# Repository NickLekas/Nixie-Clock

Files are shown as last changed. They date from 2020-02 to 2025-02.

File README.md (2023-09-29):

v1 is broken and required some bodge wires to work. I have not updated the schematic and PCB to correct my mistakes. It also has some deficencies in the dimming circuit resulint in a quiet, but audible whine.

v2 is in progress and will fix many issues and make the clock easier to update. It wil be using an RP2040.

Features
- Automatic time seting using GPS
- User sets their time zone using dip switches
- Tubes dim with ambient light
- Day light savings time will be controlled using a +/-1 switch 
- Plenty of test points for testing and hacking
- USB C for power and data

The goal of this is to be a program once project so the end user will never need to plug it into a computer. But if they do, the RP2040 will make firmware updates easy

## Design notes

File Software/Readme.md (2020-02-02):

This is the initial code for an Arduino Mega based Nixie tube based clock. 

This clock consists of a GPS module to set time and a DS3231SN RTC to keep track of time.

On startup, the gps module will get the current time and send it to the RTC. Once the RTC has the time, the GPS module will be powerd down to save energy.

Every night at 3am local time, the GPS will be turned back on and update the RTC time. While the DS3231SN is a very precise RTC, this is done for good measure. Depending on the clocks location, it is possible that the gps will not be able to aquire a signal. After 10 minutes of not aquiring a signal, the GPS will be turned off and an attempt to set the time will be made the next day.

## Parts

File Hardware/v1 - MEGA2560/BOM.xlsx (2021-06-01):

v1.0
Ref des | Quantity | value | Component | Package
C1, C2, C3, C4, C6, C10, C11 | 7 | 0.1uF |  | 0603 | 1
C17, C18 | 2 | 0.22uF |  | 0603 | 1
C13 | 1 | 100uF |  | 0603
C5, C9, C12, C16 | 4 | 10uF |  | 0603 | 1
C7, C8, C15 | 3 | 1uF |  | 0603 | 1
C14 | 1 | 4.7uf | 200V + | E3,5-8 | 1
R7, R8, R9, R16 | 4 | 100k | 1/3 W | 0603 | 1
R1, R3, R4, R5, R6, R10, R11, R17, R18, R19, R20, R21, R22 | 13 | 10k |  | 0603 | 1
R12, R13, R14, R15 | 4 | 10k | 1/2 W | 0805 | 1
R2 | 1 | 1M |  | 0603 | 1
D1, D2 | 2 | Green |  | 0603 | 1
U3, U4, U5, U6 | 4 |  | K155ID1 | DIP 16 | 1
U1 | 1 |  | ATmega2560-16AU | TQFP100 | 1
U2 | 1 |  | CH340C | SOP-16 |  | lcsc | https://lcsc.com/product-detail/USB-ICs_WCH-Jiangsu-Qin-Heng-CH340C_C84681.html
U8 | 1 |  | DS3231SN#T&R | SOIC-16 | 1
U12 | 1 |  | IP2721 | TSSOP-16 | 1 | lcsc | https://lcsc.com/product-detail/Interface-Specialized_INJOINIC-IP2721_C603176.html
U11 | 1 |  | L80-M39 | LCC | 1 | lcsc | https://lcsc.com/product-detail/Satellite-Positioning-Modules_Quectel-L80-M39_C133488.html
U13, U14 | 2 |  | LM340MP-5.0/NOPB | SOT-223 | 1
U9, U10 | 2 |  | MIC5205-3.3YM5-TR | SOT-23-5 |  | lcsc
U7 | 1 |  | NCH8200HV |  | 1
S1 | 1 |  | SW_DIP-8 | DIP-16 | 1
T3 | 1 |  | CSD18543Q3A | VSONP-8 | 1
T1 | 1 |  | PZTA92 | SOT-223 | 1
T2 | 1 |  | PZTA42 | SOT-223 | 1
PH1 | 1 |  | GM5539 |  | 1
BT1 | 1 |  | 1056 or CR1220-2 |  | 1
X1 | 1 |  | CSTNE16M0V53C000R0 |  | 1
J4 | 1 |  | HRO_TYPE-C-31-M-12 |  |  | lcsc | https://lcsc.com/product-detail/USB-Connectors_Hanbo-Electronic-MC-312_C961716.html
N1, N2, N3, N4 | 4 |  | ИН-8 |  | 1
v1.05
Ref des | Quantity | value | Component | Package
C1, C2, C3, C4, C6, C10, C11 | 7 | 0.1uF |  | 0603
C17, C18 | 2 | 0.22uF |  | 0603
C13 | 1 | 100uF |  | 0603
C5, C9, C12, C16 | 4 | 10uF |  | 0603
C7, C8, C15 | 3 | 1uF |  | 0603
C14 | 1 | 4.7uf | 200V + | E3,5-8
R7, R8, R9, R16 | 4 | 100k | 1/3 W | 0603
R1, R10, R11, R17, R18, R20, R22 | 7 | 10k |  | 0603
R3, R4, R5, R6, R19 | 5 | 5.1k |  | 0603
R12, R13, R14, R15 | 4 | 10k | 1/2 W | 0805
R2 | 1 | 1M |  | 0603
D1, D2 | 2 | Green |  | 0603
U3, U4, U5, U6 | 4 |  | K155ID1 | DIP 16
U1 | 1 |  | ATmega2560-16AU | TQFP100
U2 | 1 |  | CH340C | SOP-16 | lcsc | https://lcsc.com/product-detail/USB-ICs_WCH-Jiangsu-Qin-Heng-CH340C_C84681.html
U8 | 1 |  | DS3231SN#T&R | SOIC-16
U12 | 1 |  | IP2721 | TSSOP-16 | lcsc | https://lcsc.com/product-detail/Interface-Specialized_INJOINIC-IP2721_C603176.html
U11 | 1 |  | L80-M39 | LCC | lcsc | https://lcsc.com/product-detail/Satellite-Positioning-Modules_Quectel-L80-M39_C133488.html
U13, U14 | 2 |  | LM340MP-5.0/NOPB | SOT-223
U9, U10 | 2 |  | MIC5205-3.3YM5-TR | SOT-23-5 | lcsc
U7 | 1 |  | NCH8200HV
S1 | 1 |  | SW_DIP-8 | DIP-16
T3 | 1 |  | CSD18543Q3A | VSONP-8
T1 | 1 |  | PZTA92 | SOT-223
T2 | 1 |  | PZTA42 | SOT-223
PH1 | 1 |  | GM5539
BT1 | 1 |  | 1056 or CR1220-2
X1 | 1 |  | CSTNE16M0V53C000R0
J4 | 1 |  | 12402012E212A
N1, N2, N3, N4 | 4 |  | ИН-8

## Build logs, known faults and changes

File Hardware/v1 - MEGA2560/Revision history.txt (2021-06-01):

v1.0
	- Initial design
v1.05 (This version fixed some issues in v1.0 before switching to KiCad)
	- Changed all polygon pours to not have thermal connections
	- Changed D1, D2 to have 5.1k current limiting resistors
	- Added 5.1k pull downs to CC1, CC2
	- Reduced the RX voltage divider to a 10K and 5.1K
v1.1 (Carries over all fixes made in v1.0)
	- Switched design to KiCad v6/5.99

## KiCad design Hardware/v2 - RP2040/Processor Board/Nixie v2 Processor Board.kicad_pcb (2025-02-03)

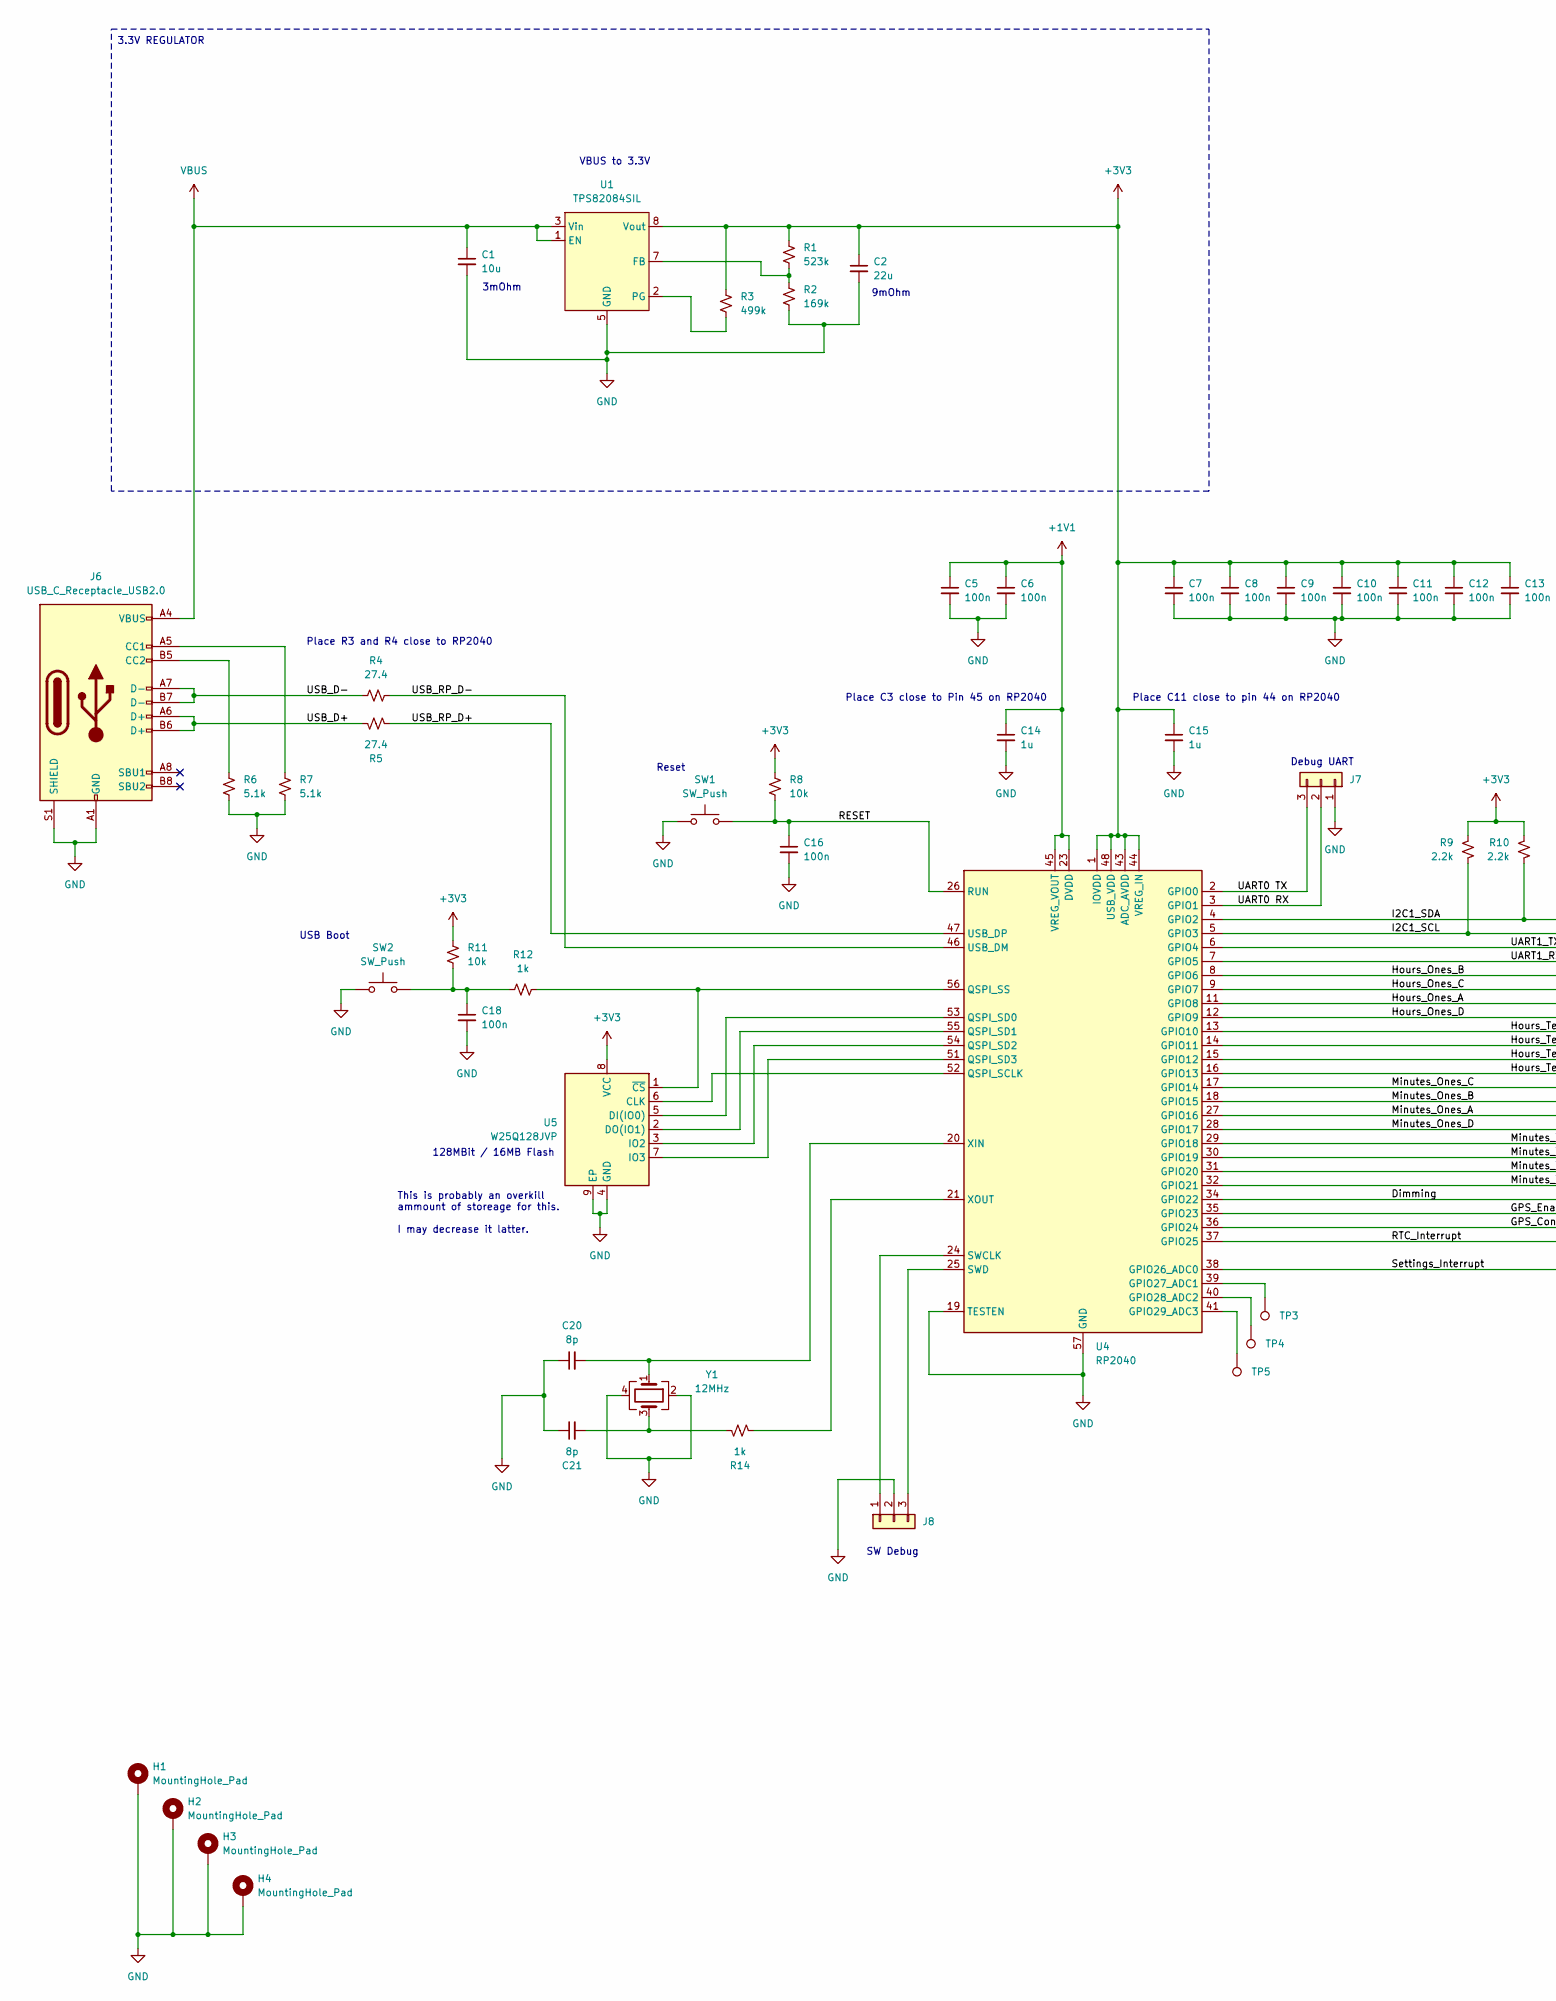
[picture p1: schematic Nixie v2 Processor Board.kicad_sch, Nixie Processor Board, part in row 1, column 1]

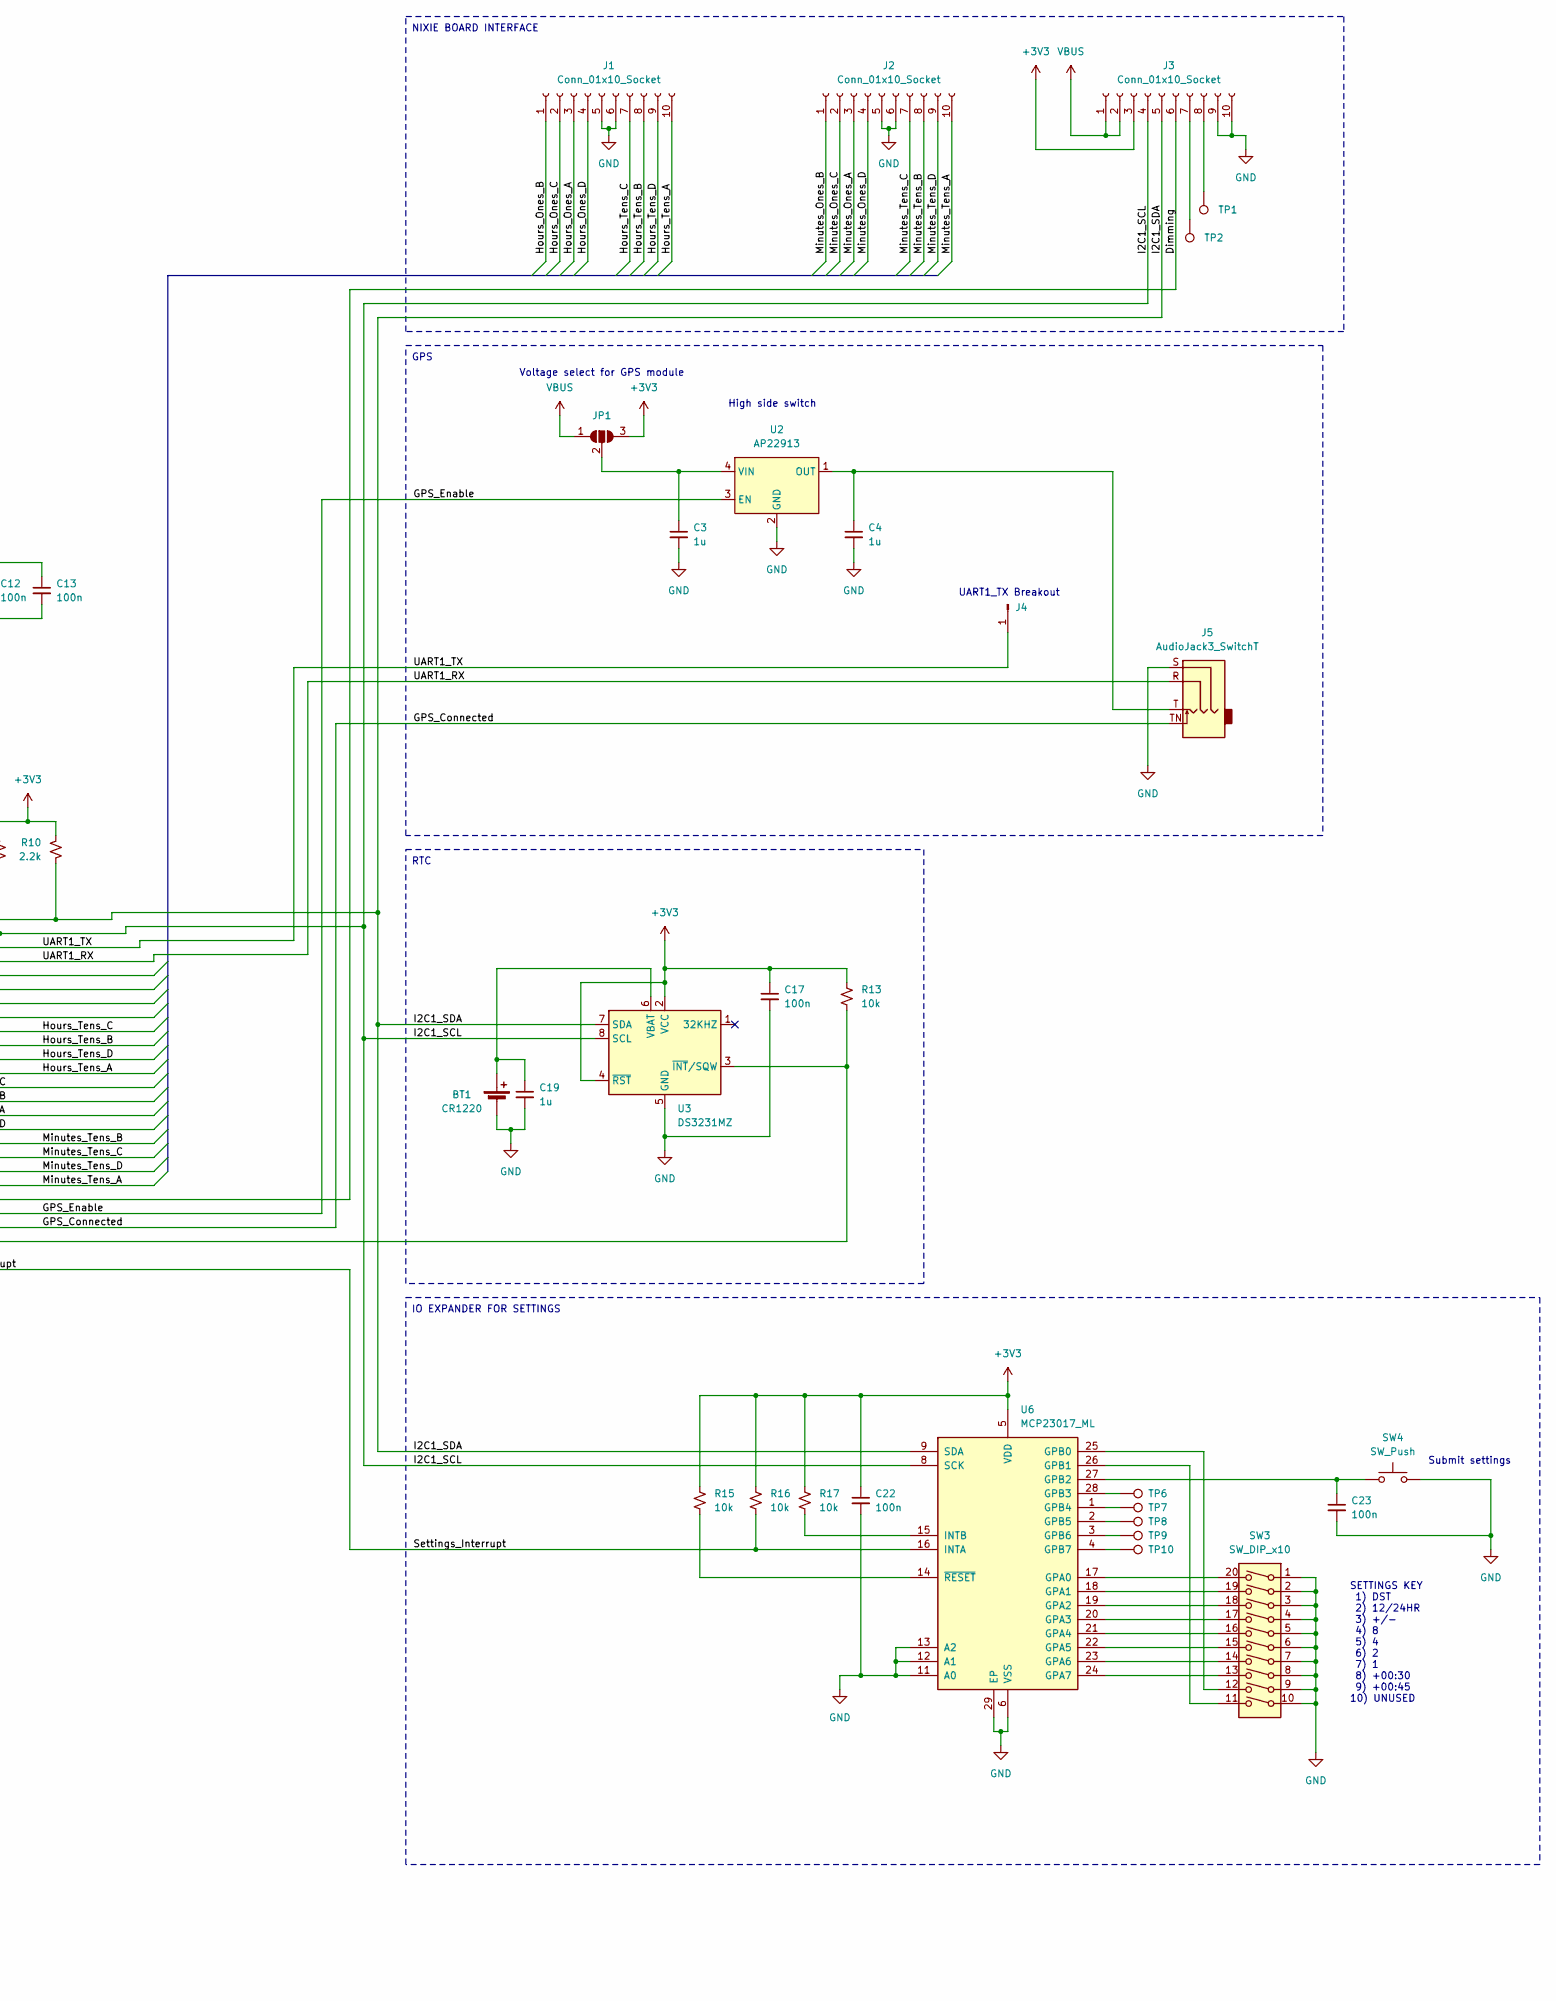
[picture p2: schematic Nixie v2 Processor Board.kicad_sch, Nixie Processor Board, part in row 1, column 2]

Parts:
BT1: CR1220; BatteryHolder_LINX_BAT-HLD-012-SMT; MPN BK-916-TR
C1: 10u; C_0603_1608Metric
C2: 22u; C_0603_1608Metric
C3, C4, C19: 1u; C_0603_1608Metric
C5, C6, C7, C8, C9, C10, C11, C12, C13: 100n; C_0402_1005Metric
C14, C15: 1u; C_0402_1005Metric
C16, C17, C18, C22, C23: 100n; C_0603_1608Metric
C20, C21: 8p; C_0402_1005Metric
H1, H2, H3, H4: MountingHole_Pad; MountingHole_3.2mm_M3_Pad_Via
J1, J2, J3: Conn_01x10_Socket; PinSocket_2x05_P2.54mm_Vertical
J4: Conn_01x01_Pin; PinHeader_1x01_P2.54mm_Vertical
J5: AudioJack3_SwitchT; Jack_3.5mm_CUI_SJ-3524-SMT_Horizontal
J6: USB_C_Receptacle_USB2.0; USB_C_Receptacle_HRO_TYPE-C-31-M-12
J7, J8: Conn_01x03_2.54mm; PinHeader_1x03_P2.54mm_Vertical
JP1: SolderJumper_3_Open; SolderJumper-3_P1.3mm_Open_RoundedPad1.0x1.5mm_NumberLabels
R1: 523k; R_0603_1608Metric
R2: 169k; R_0603_1608Metric
R3: 499k; R_0603_1608Metric
R4, R5: 27.4; R_0402_1005Metric
R6, R7: 5.1k; R_0603_1608Metric
R8, R11, R13, R15, R16, R17: 10k; R_0603_1608Metric
R9, R10: 2.2k; R_0603_1608Metric
R12: 1k; R_0603_1608Metric
R14: 1k; R_0402_1005Metric
SW1, SW2, SW4: SW_Push; SW_Push_1P1T_NO_CK_KMR2; MPN KMR213G LFG
SW3: SW_DIP_x10; SW_DIP_SPSTx10_Piano_10.8x26.96mm_W7.62mm_P2.54mm; MPN 219-10MST
TP1, TP2, TP3, TP4, TP5, TP6, TP7, TP8, TP9, TP10: TestPoint; TestPoint_Pad_D2.0mm
U1: TPS82084SIL; MicroSiP 1.33mm
U2: AP22913; SOT-23-6
U3: DS3231MZ; SOIC-8_3.9x4.9mm_P1.27mm
U4: RP2040; QFN-56-1EP_7x7mm_P0.4mm_EP3.2x3.2mm
U5: W25Q128JVP; WSON-8-1EP_6x5mm_P1.27mm_EP3.4x4.3mm
U6: MCP23017_ML; QFN-28-1EP_6x6mm_P0.65mm_EP4.25x4.25mm
Y1: 12MHz; Crystal_SMD_Abracon_ABM10-4Pin_2.5x2.0mm; MPN ABM10-166-12.000MHZ-T3

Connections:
+1V1: C5.1, C6.1, C14.1, U4.23 (DVDD), U4.45 (VREG_VOUT), U4.50 (DVDD)
+3V3: C2.1, C7.1, C8.1, C9.1, C10.1, C11.1, C12.1, C13.1, C15.1, C17.1, C22.1, J3.3, JP1.3 (B), R1.2, R3.2, R8.2, R9.1, R10.1, R11.2, R13.1, R15.1, R16.1, R17.1, U1.8 (Vout), U3.2 (VCC), U3.4 (~RST), U4.1 (IOVDD), U4.10 (IOVDD), U4.22 (IOVDD), U4.33 (IOVDD), U4.42 (IOVDD), U4.43 (ADC_AVDD), U4.44 (VREG_IN), U4.48 (USB_VDD), U4.49 (IOVDD), U5.8 (VCC), U6.5 (VDD)
/Dimming: J3.6, U4.34 (GPIO22)
/GPS_Connected: J5.TN, U4.36 (GPIO24)
/GPS_Enable: U2.3 (EN), U4.35 (GPIO23)
/Hours_Ones_A: J1.3, U4.11 (GPIO8)
/Hours_Ones_B: J1.1, U4.8 (GPIO6)
/Hours_Ones_C: J1.2, U4.9 (GPIO7)
/Hours_Ones_D: J1.4, U4.12 (GPIO9)
/Hours_Tens_A: J1.10, U4.16 (GPIO13)
/Hours_Tens_B: J1.8, U4.14 (GPIO11)
/Hours_Tens_C: J1.7, U4.13 (GPIO10)
/Hours_Tens_D: J1.9, U4.15 (GPIO12)
/I2C1_SCL: J3.4, R9.2, U3.8 (SCL), U4.5 (GPIO3), U6.8 (SCK)
/I2C1_SDA: J3.5, R10.2, U3.7 (SDA), U4.4 (GPIO2), U6.9 (SDA)
/Minutes_Ones_A: J2.3, U4.27 (GPIO16)
/Minutes_Ones_B: J2.1, U4.18 (GPIO15)
/Minutes_Ones_C: J2.2, U4.17 (GPIO14)
/Minutes_Ones_D: J2.4, U4.28 (GPIO17)
/Minutes_Tens_A: J2.10, U4.32 (GPIO21)
/Minutes_Tens_B: J2.8, U4.29 (GPIO18)
/Minutes_Tens_C: J2.7, U4.30 (GPIO19)
/Minutes_Tens_D: J2.9, U4.31 (GPIO20)
/RESET: C16.1, R8.1, SW1.2, U4.26 (RUN)
/RTC_Interrupt: R13.2, U3.3 (~INT/SQW), U4.37 (GPIO25)
/Settings_Interrupt: R16.2, U4.38 (GPIO26_ADC0), U6.16 (INTA)
/UART0 RX: J7.2, U4.3 (GPIO1)
/UART0 TX: J7.3, U4.2 (GPIO0)
/UART1_RX: J5.R, U4.7 (GPIO5)
/UART1_TX: J4.1, U4.6 (GPIO4)
/USB_D+: J6.A6 (D+), J6.B6 (D+), R5.2
/USB_D-: J6.A7 (D-), J6.B7 (D-), R4.2
/USB_RP_D+: R5.1, U4.47 (USB_DP)
/USB_RP_D-: R4.1, U4.46 (USB_DM)
GND: BT1.2 (-), C1.2, C2.2, C3.2, C4.2, C5.2, C6.2, C7.2, C8.2, C9.2, C10.2, C11.2, C12.2, C13.2, C14.2, C15.2, C16.2, C17.2, C18.2, C19.2, C20.1, C21.1, C22.2, C23.2, H1.1, H2.1, H3.1, H4.1, J1.5, J1.6, J2.5, J2.6, J3.9, J3.10, J5.S, J6.A1 (GND), J6.A12 (GND), J6.B1 (GND), J6.B12 (GND), J6.S1 (SHIELD), J7.1, J8.2, R2.1, R6.1, R7.1, SW1.1, SW2.1, SW3.1, SW3.2, SW3.3, SW3.4, SW3.5, SW3.6, SW3.7, SW3.8, SW3.9, SW3.10, SW4.2, U1.5 (GND), U1.6 (GND), U1.9 (GND), U2.2 (GND), U2.5 (GND), U3.5 (GND), U4.19 (TESTEN), U4.57 (GND), U5.4 (GND), U5.9 (EP), U6.6 (VSS), U6.11 (A0), U6.12 (A1), U6.13 (A2), U6.29 (EP), Y1.2, Y1.4
unnamed: BT1.1 (+), C19.1, U3.6 (VBAT)
unnamed: C18.1, R11.1, R12.2, SW2.2
unnamed: C21.2, R14.2, Y1.3
unnamed: J3.7, TP2.1
unnamed: J3.8, TP1.1
unnamed: J6.A5 (CC1), R7.2
unnamed: J6.B5 (CC2), R6.2
unnamed: J8.1, U4.24 (SWCLK)
unnamed: J8.3, U4.25 (SWD)
unnamed: C3.1, JP1.2 (C), U2.4 (VIN), U2.6 (VIN)
unnamed: R1.1, R2.2, U1.7 (FB)
unnamed: R3.1, U1.2 (PG)
unnamed: C4.1, J5.T, U2.1 (OUT)
unnamed: TP3.1, U4.39 (GPIO27_ADC1)
unnamed: TP4.1, U4.40 (GPIO28_ADC2)
unnamed: TP5.1, U4.41 (GPIO29_ADC3)
unnamed: U4.52 (QSPI_SCLK), U5.6 (CLK)
unnamed: U4.53 (QSPI_SD0), U5.5 (DI(IO0))
unnamed: U4.55 (QSPI_SD1), U5.2 (DO(IO1))
unnamed: U4.54 (QSPI_SD2), U5.3 (IO2)
unnamed: U4.51 (QSPI_SD3), U5.7 (IO3)
unnamed: R12.1, U4.56 (QSPI_SS), U5.1 (~CS)
unnamed: C20.2, U4.20 (XIN), Y1.1
unnamed: R14.1, U4.21 (XOUT)
unnamed: SW3.20, U6.17 (GPA0)
unnamed: SW3.19, U6.18 (GPA1)
unnamed: SW3.18, U6.19 (GPA2)
unnamed: SW3.17, U6.20 (GPA3)
unnamed: SW3.16, U6.21 (GPA4)
unnamed: SW3.15, U6.22 (GPA5)
unnamed: SW3.14, U6.23 (GPA6)
unnamed: SW3.13, U6.24 (GPA7)
unnamed: SW3.12, U6.25 (GPB0)
unnamed: SW3.11, U6.26 (GPB1)
unnamed: C23.1, SW4.1, U6.27 (GPB2)
unnamed: TP6.1, U6.28 (GPB3)
unnamed: TP7.1, U6.1 (GPB4)
unnamed: TP8.1, U6.2 (GPB5)
unnamed: TP9.1, U6.3 (GPB6)
unnamed: TP10.1, U6.4 (GPB7)
unnamed: R17.2, U6.15 (INTB)
unnamed: R15.2, U6.14 (~RESET)
VBUS: C1.1, J3.1, J3.2, J6.A4 (VBUS), J6.A9 (VBUS), J6.B4 (VBUS), J6.B9 (VBUS), JP1.1 (A), U1.1 (EN), U1.3 (Vin), U1.4 (Vin)

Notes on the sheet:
SW Debug
Place C11 close to pin 44 on RP2040
9mOhm
This is probably an overkill ammount of storeage for this. I may decrease it latter.
RTC
3mOhm
Voltage select for GPS module
GPS
Debug UART
Submit settings
High side switch
USB Boot
Place C3 close to Pin 45 on RP2040
Place R3 and R4 close to RP2040
128MBit / 16MB Flash
NIXIE BOARD INTERFACE
UART1_TX Breakout
3.3V REGULATOR
SETTINGS KEY 1) DST 2) 12/24HR 3) +/- 4) 8 5) 4 6) 2 7) 1 8) +00:30 9) +00:45 10) UNUSED
VBUS to 3.3V
IO EXPANDER FOR SETTINGS
Reset

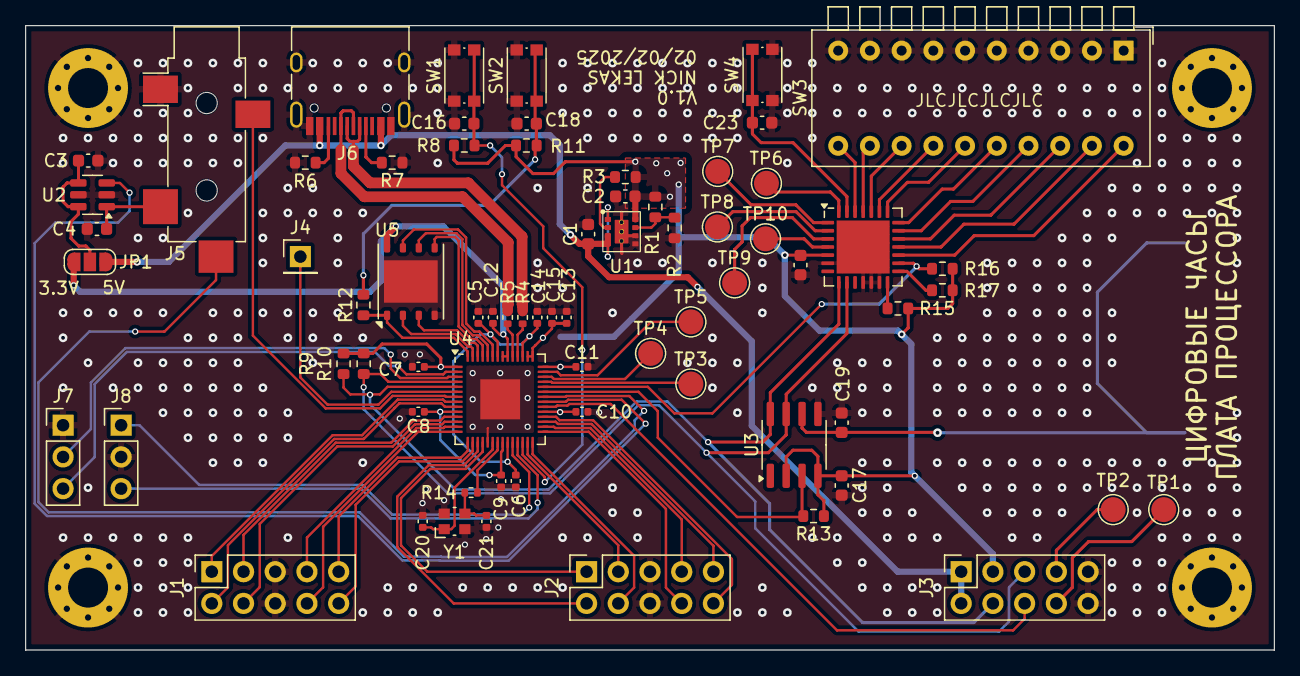
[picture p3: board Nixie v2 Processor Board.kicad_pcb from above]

Board: 2 copper layers, 100.0 x 50.0 mm, 75 parts (1 on the bottom side), 78 nets.

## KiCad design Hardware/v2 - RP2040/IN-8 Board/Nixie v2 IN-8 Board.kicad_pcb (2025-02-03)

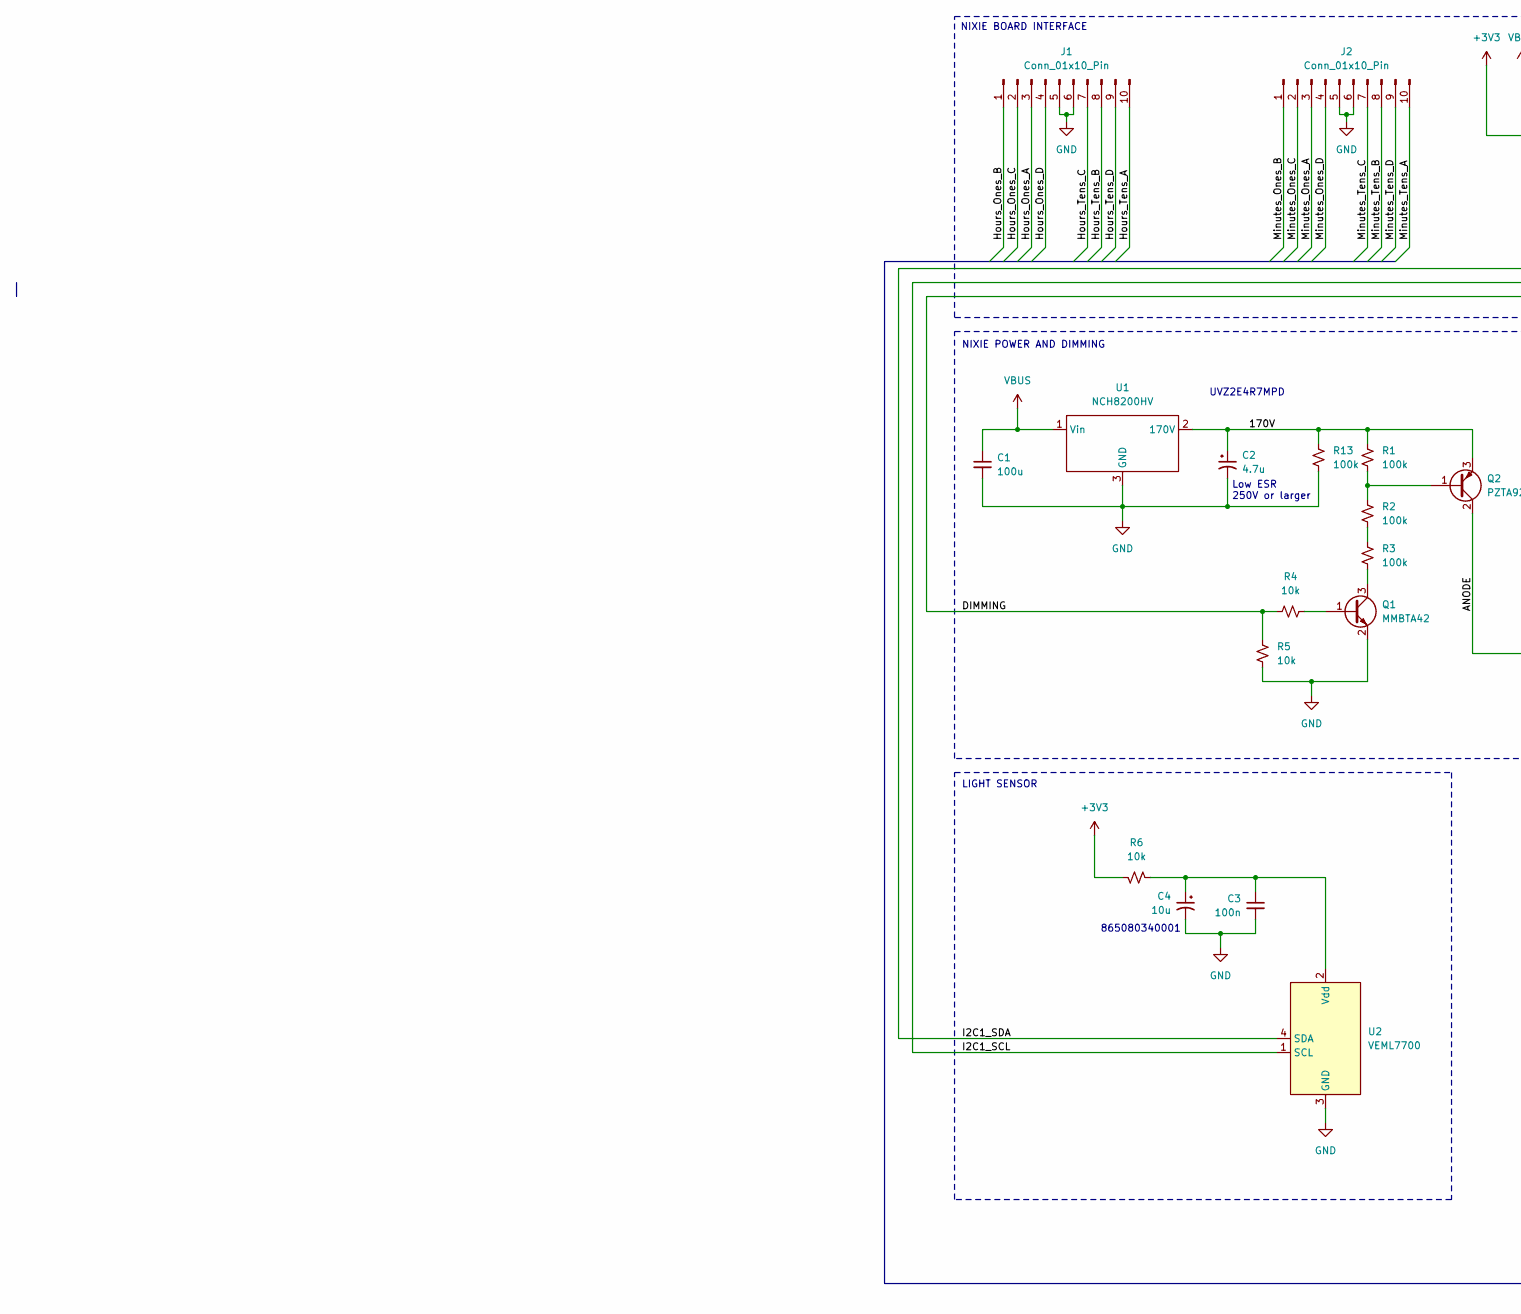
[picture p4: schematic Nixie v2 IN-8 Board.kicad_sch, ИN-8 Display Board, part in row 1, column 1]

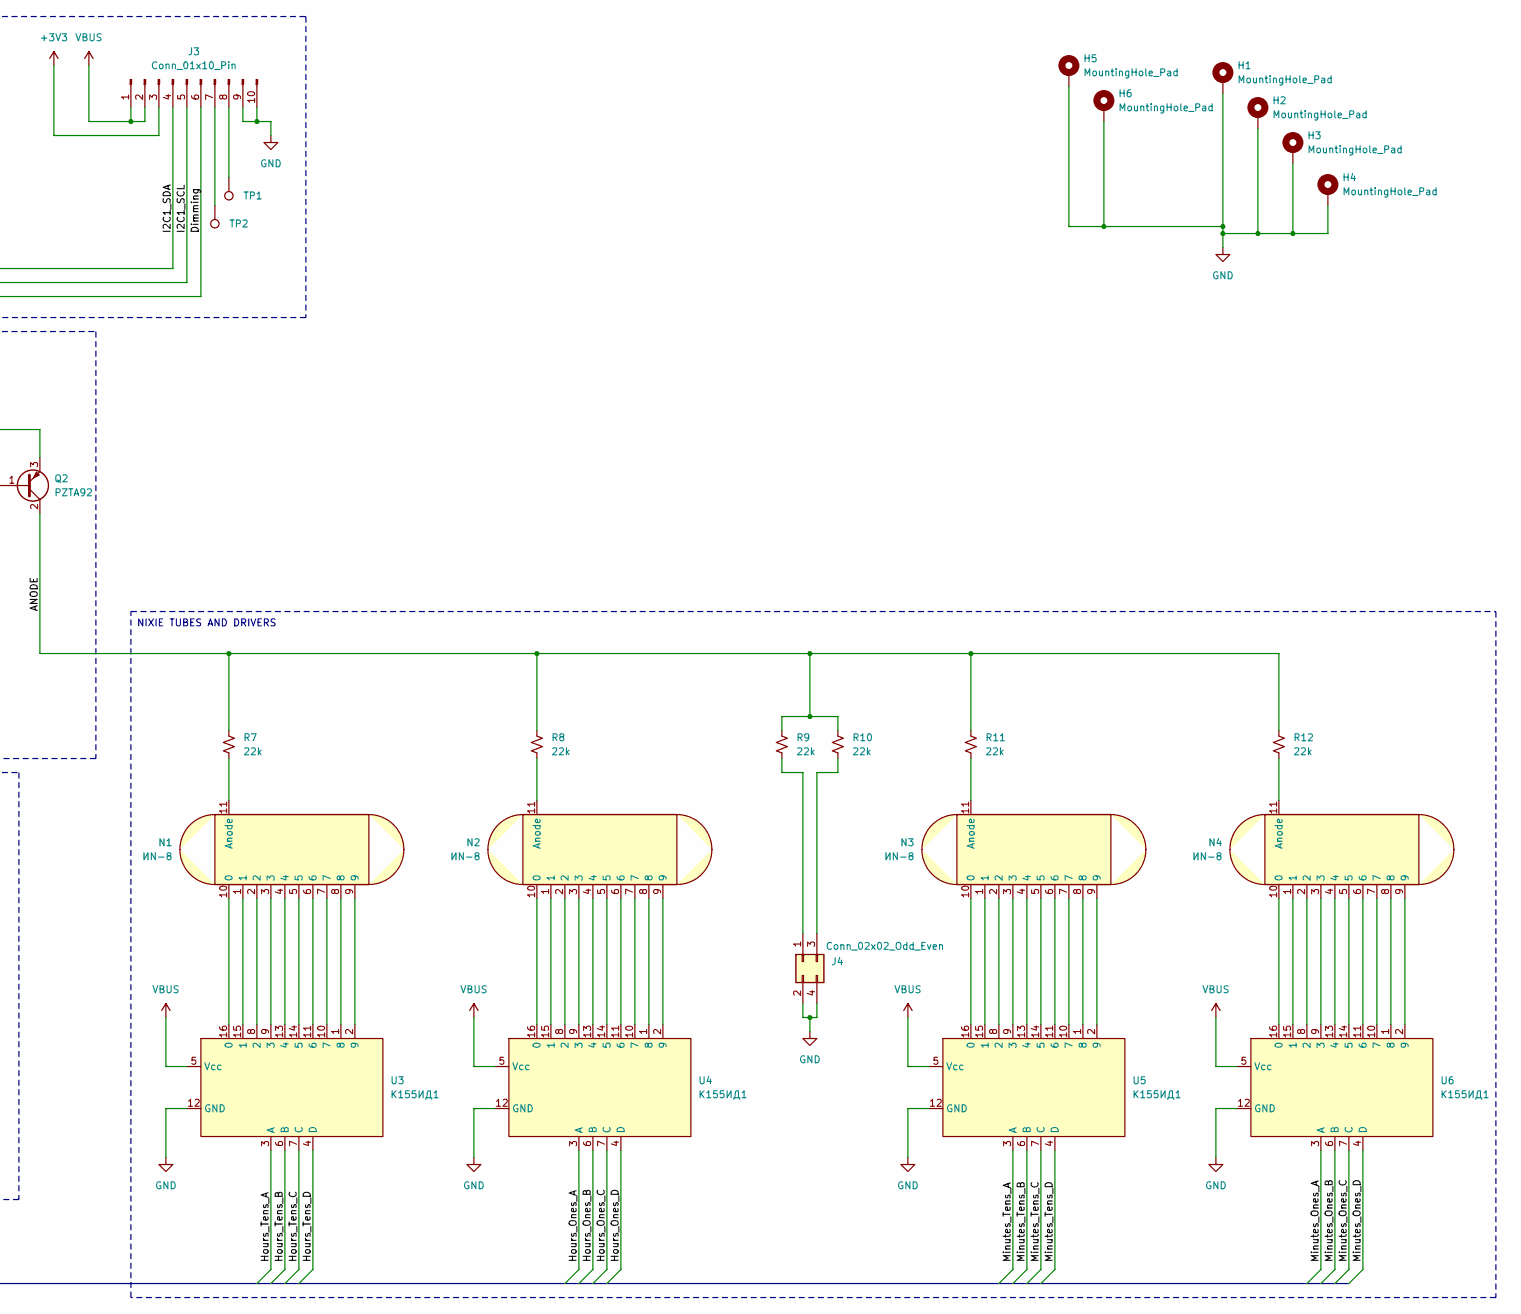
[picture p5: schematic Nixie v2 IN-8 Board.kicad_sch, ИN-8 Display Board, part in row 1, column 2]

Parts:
C1: 100u; C_0603_1608Metric
C2: 4.7u; CP_Radial_D8.0mm_P3.50mm
C3: 100n; C_0603_1608Metric
C4: 10u; CP_Elec_4x5.4
H1, H2, H3, H4, H5, H6: MountingHole_Pad; MountingHole_3.2mm_M3_Pad_Via
J1, J2, J3: Conn_01x10_Pin; PinHeader_2x05_P2.54mm_Vertical
J4: Conn_02x02_Odd_Even; PinSocket_2x02_P2.54mm_Vertical
N1, N2, N3, N4: ИN-8
Q1: MMBTA42; SOT-23
Q2: PZTA92; SOT-223-3_TabPin2
R1, R2, R3: 100k; R_0603_1608Metric
R4, R5, R6: 10k; R_0603_1608Metric
R7, R8, R9, R10, R11, R12: 22k; R_0805_2012Metric
R13: 100k; R_0805_2012Metric
TP1, TP2: TestPoint; TestPoint_Pad_D2.0mm
U1: NCH8200HV
U2: VEML7700; VEML7700-TV
U3, U4, U5, U6: К155ИД1; DIP-16_W7.62mm

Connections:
+3V3: J3.3, R6.2
/170V: C2.1, Q2.3 (E), R1.1, R13.1, U1.2 (170V)
/ANODE: Q2.2 (C), R7.1, R8.1, R9.1, R10.1, R11.1, R12.1
/DIMMING: J3.6, R4.1, R5.1
/Hours_Ones_A: J1.3, U4.3 (A)
/Hours_Ones_B: J1.1, U4.6 (B)
/Hours_Ones_C: J1.2, U4.7 (C)
/Hours_Ones_D: J1.4, U4.4 (D)
/Hours_Tens_A: J1.10, U3.3 (A)
/Hours_Tens_B: J1.8, U3.6 (B)
/Hours_Tens_C: J1.7, U3.7 (C)
/Hours_Tens_D: J1.9, U3.4 (D)
/I2C1_SCL: J3.5, U2.1 (SCL)
/I2C1_SDA: J3.4, U2.4 (SDA)
/Minutes_Ones_A: J2.3, U6.3 (A)
/Minutes_Ones_B: J2.1, U6.6 (B)
/Minutes_Ones_C: J2.2, U6.7 (C)
/Minutes_Ones_D: J2.4, U6.4 (D)
/Minutes_Tens_A: J2.10, U5.3 (A)
/Minutes_Tens_B: J2.8, U5.6 (B)
/Minutes_Tens_C: J2.7, U5.7 (C)
/Minutes_Tens_D: J2.9, U5.4 (D)
GND: C1.2, C2.2, C3.2, C4.2, H1.1, H2.1, H3.1, H4.1, H5.1, H6.1, J1.5, J1.6, J2.5, J2.6, J3.9, J3.10, J4.2, J4.4, Q1.2 (E), R5.2, R13.2, U1.3 (GND), U1.4 (GND), U2.3 (GND), U3.12 (GND), U4.12 (GND), U5.12 (GND), U6.12 (GND)
unnamed: J3.7, TP2.1
unnamed: J3.8, TP1.1
unnamed: J4.1, R9.2
unnamed: J4.3, R10.2
unnamed: N1.10 (0), U3.16 (0)
unnamed: N1.11 (Anode), R7.2
unnamed: N2.10 (0), U4.16 (0)
unnamed: N2.11 (Anode), R8.2
unnamed: N3.10 (0), U5.16 (0)
unnamed: N3.11 (Anode), R11.2
unnamed: N4.10 (0), U6.16 (0)
unnamed: N4.11 (Anode), R12.2
unnamed: Q1.1 (B), R4.2
unnamed: Q1.3 (C), R3.2
unnamed: Q2.1 (B), R1.2, R2.1
unnamed: R2.2, R3.1
unnamed: C3.1, C4.1, R6.1, U2.2 (Vdd)
unnamed: N1.1, U3.15 (1)
unnamed: N1.2, U3.8 (2)
unnamed: N1.3, U3.9 (3)
unnamed: N1.4, U3.13 (4)
unnamed: N1.5, U3.14 (5)
unnamed: N1.6, U3.11 (6)
unnamed: N1.7, U3.10 (7)
unnamed: N1.8, U3.1 (8)
unnamed: N1.9, U3.2 (9)
unnamed: N2.1, U4.15 (1)
unnamed: N2.2, U4.8 (2)
unnamed: N2.3, U4.9 (3)
unnamed: N2.4, U4.13 (4)
unnamed: N2.5, U4.14 (5)
unnamed: N2.6, U4.11 (6)
unnamed: N2.7, U4.10 (7)
unnamed: N2.8, U4.1 (8)
unnamed: N2.9, U4.2 (9)
unnamed: N3.1, U5.15 (1)
unnamed: N3.2, U5.8 (2)
unnamed: N3.3, U5.9 (3)
unnamed: N3.4, U5.13 (4)
unnamed: N3.5, U5.14 (5)
unnamed: N3.6, U5.11 (6)
unnamed: N3.7, U5.10 (7)
unnamed: N3.8, U5.1 (8)
unnamed: N3.9, U5.2 (9)
unnamed: N4.1, U6.15 (1)
unnamed: N4.2, U6.8 (2)
unnamed: N4.3, U6.9 (3)
unnamed: N4.4, U6.13 (4)
unnamed: N4.5, U6.14 (5)
unnamed: N4.6, U6.11 (6)
unnamed: N4.7, U6.10 (7)
unnamed: N4.8, U6.1 (8)
unnamed: N4.9, U6.2 (9)
VBUS: C1.1, J3.1, J3.2, U1.1 (Vin), U3.5 (Vcc), U4.5 (Vcc), U5.5 (Vcc), U6.5 (Vcc)

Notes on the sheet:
NIXIE POWER AND DIMMING
LIGHT SENSOR
NIXIE BOARD INTERFACE
Low ESR 250V or larger
NIXIE TUBES AND DRIVERS
UVZ2E4R7MPD
865080340001

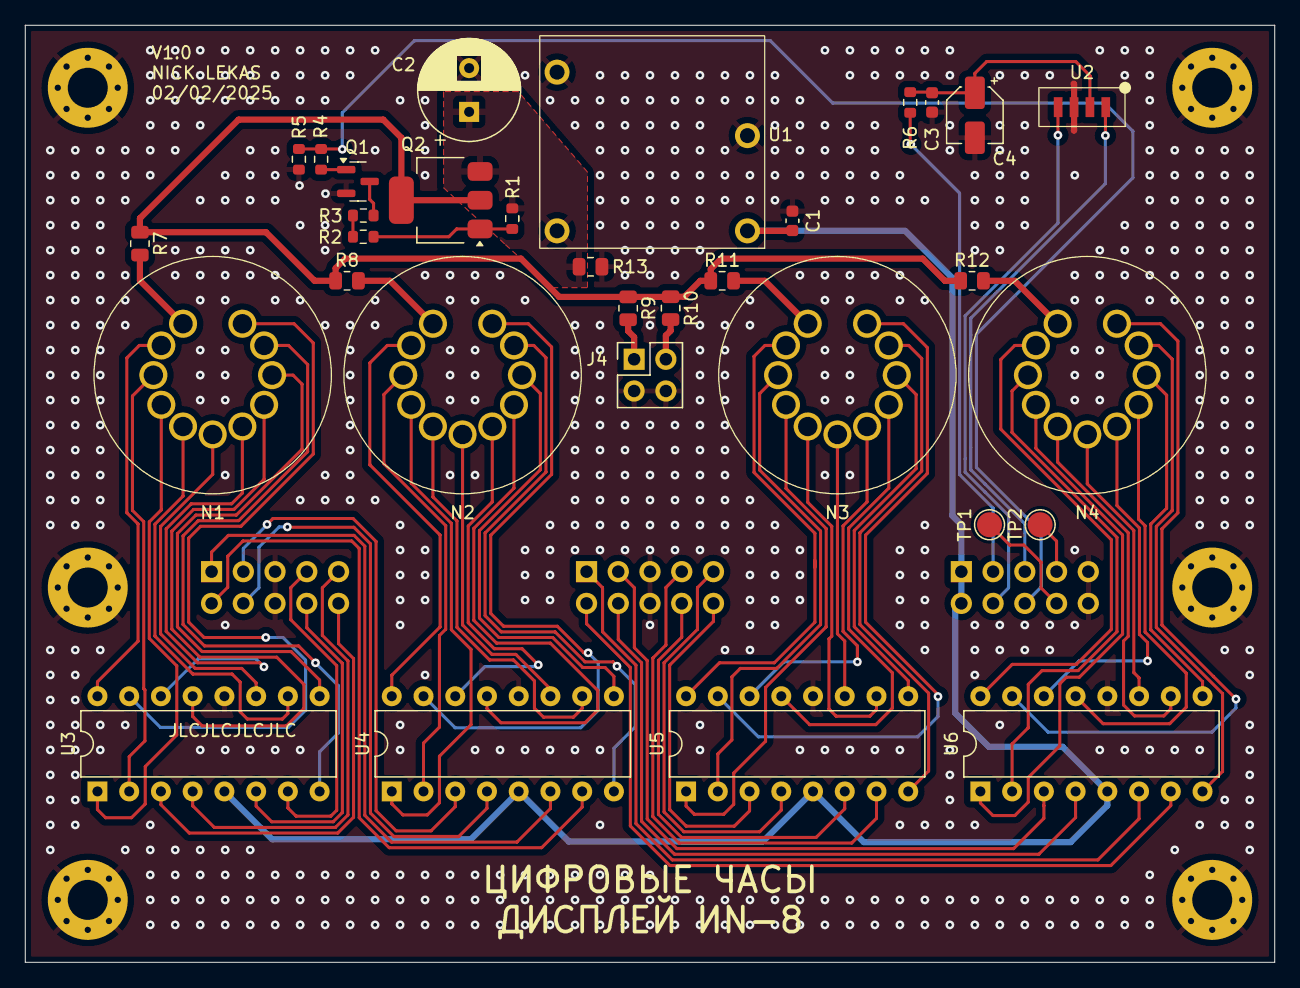
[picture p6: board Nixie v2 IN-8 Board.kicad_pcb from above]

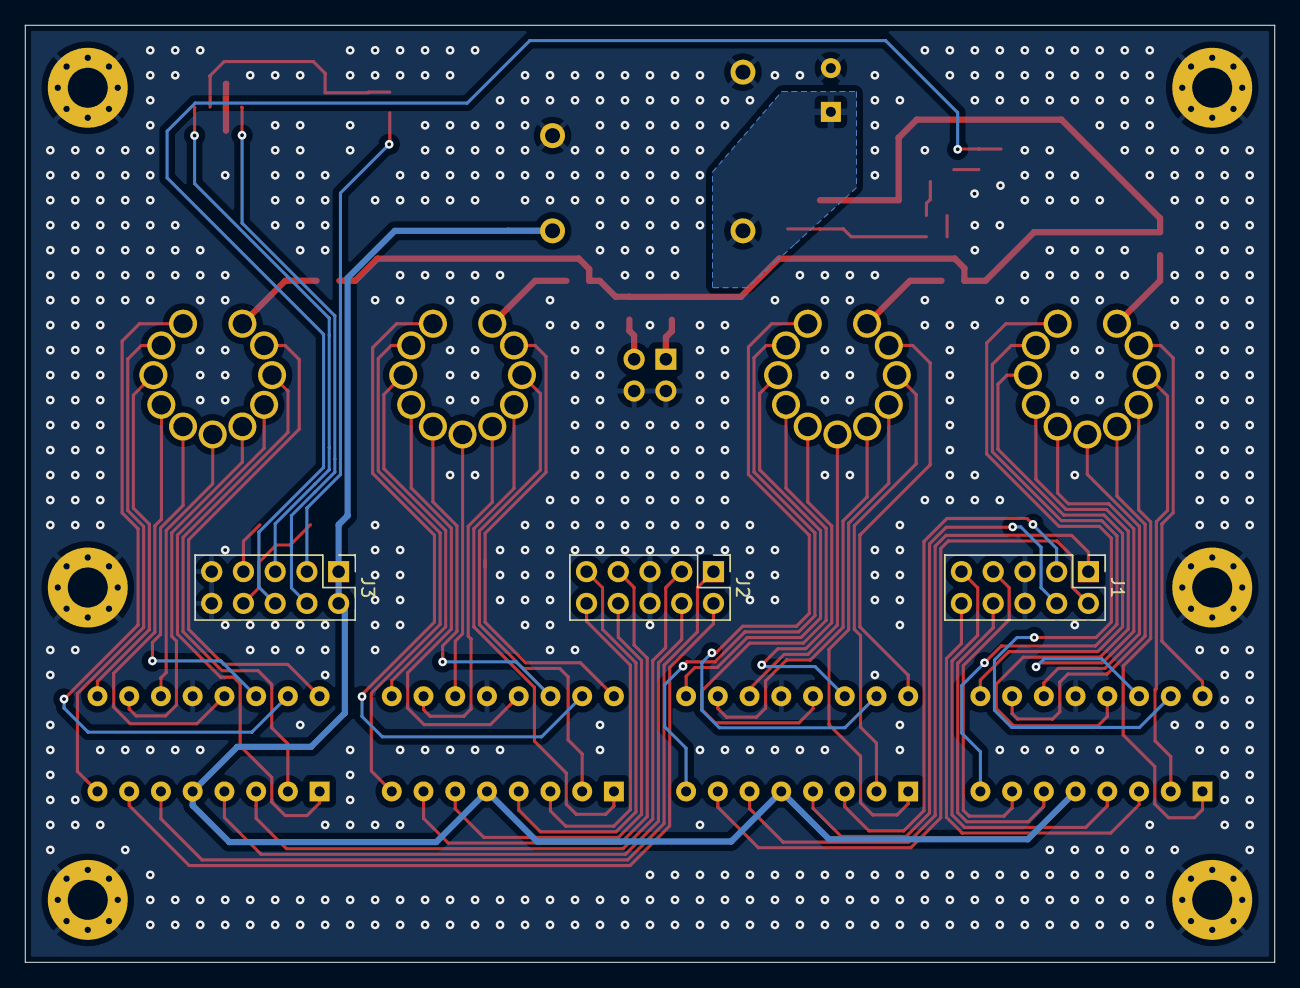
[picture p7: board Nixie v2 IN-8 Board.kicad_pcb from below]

Board: 2 copper layers, 100.0 x 75.0 mm, 41 parts (3 on the bottom side), 77 nets.

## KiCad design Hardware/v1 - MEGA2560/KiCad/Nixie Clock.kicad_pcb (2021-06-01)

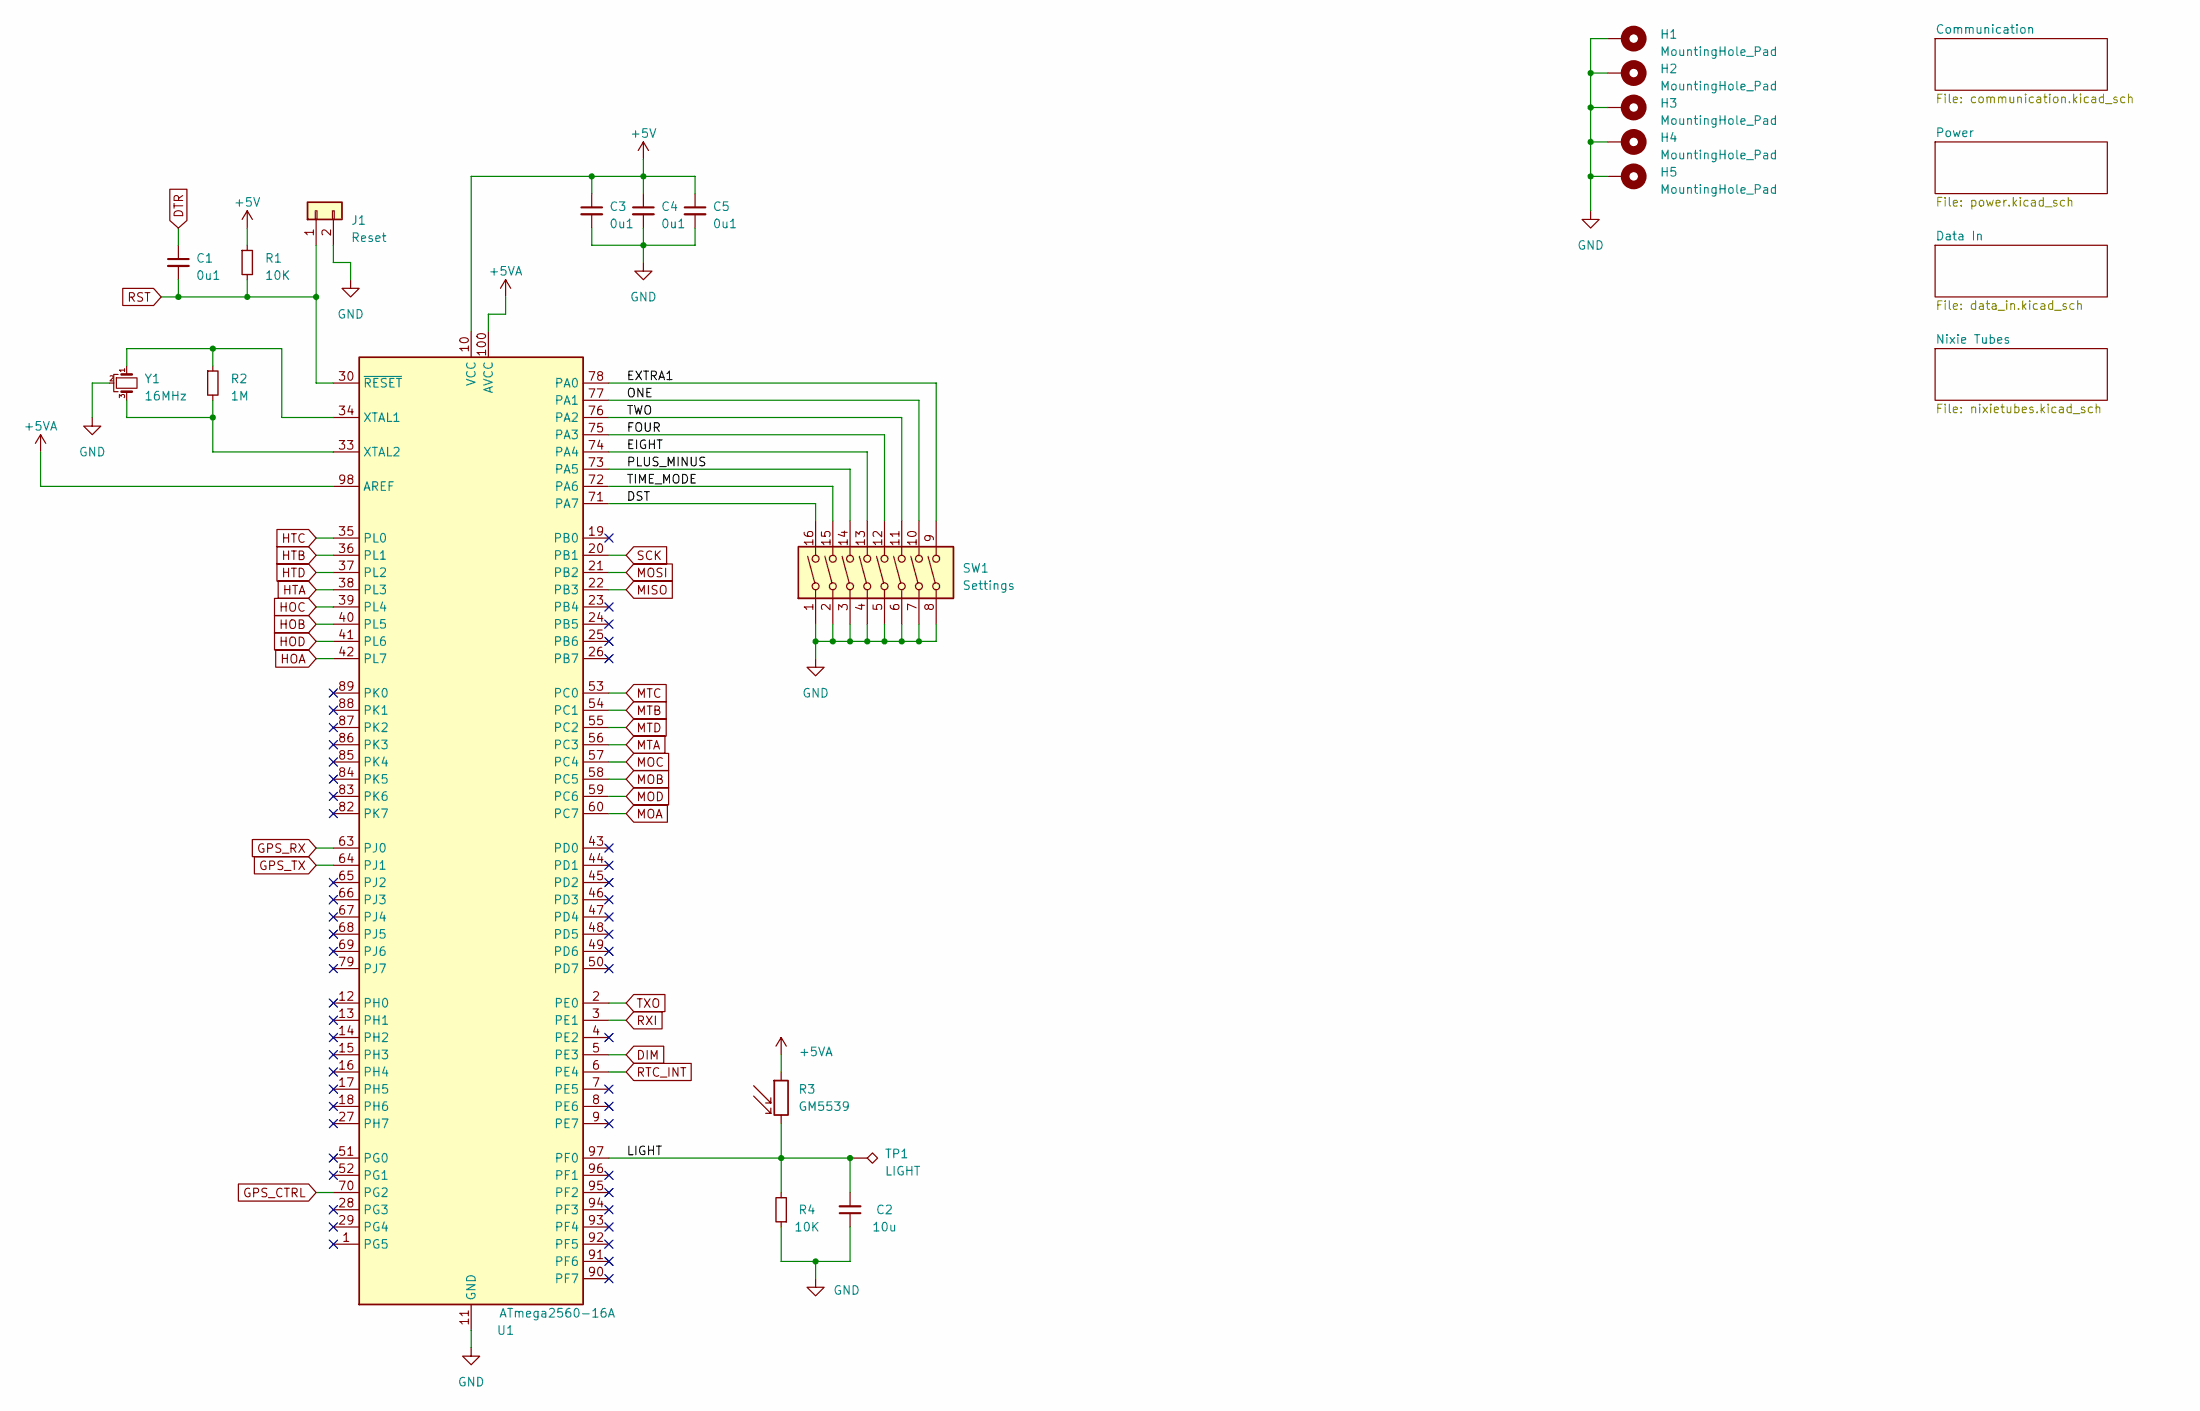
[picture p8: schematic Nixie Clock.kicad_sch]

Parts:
C1, C3, C4, C5: 0u1; C_0603_1608Metric
C2: 10u; C_0603_1608Metric
H1, H2, H3, H4, H5: MountingHole_Pad; MountingHole_3.2mm_M3_Pad_Via
J1: Reset; PinSocket_1x02_P2.54mm_Vertical
R1, R4: 10K; R_0603_1608Metric
R2: 1M; R_0603_1608Metric
R3: GM5539; R_LDR_5.1x4.3mm_P3.4mm_Vertical
SW1: Settings; SW_DIP_SPSTx08_Slide_9.78x22.5mm_W7.62mm_P2.54mm
TP1: LIGHT; TestPoint_THTPad_D2.0mm_Drill0.9mm
U1: ATmega2560-16A; TQFP-100_14x14mm_P0.5mm
Y1: 16MHz; Resonator_SMD_Murata_CSTxExxV-3Pin_3.0x1.1mm

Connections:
+5V: C3.1, C4.1, C5.1, R1.1, U1.10 (VCC), U1.31 (VCC), U1.61 (VCC), U1.80 (VCC); also elsewhere on the board
+5VA: R3.1, U1.98 (AREF), U1.100 (AVCC); also elsewhere on the board
/DST: SW1.16, U1.71 (PA7)
/EIGHT: SW1.13, U1.74 (PA4)
/EXTRA1: SW1.9, U1.78 (PA0)
/FOUR: SW1.12, U1.75 (PA3)
/LIGHT: C2.2, R3.2, R4.2, TP1.1, U1.97 (PF0)
/ONE: SW1.10, U1.77 (PA1)
/PLUS_MINUS: SW1.14, U1.73 (PA5)
/TIME_MODE: SW1.15, U1.72 (PA6)
/TWO: SW1.11, U1.76 (PA2)
DIM: U1.5 (PE3); also elsewhere on the board
DTR: C1.1; also elsewhere on the board
GND: C2.1, C3.2, C4.2, C5.2, H1.1, H2.1, H3.1, H4.1, H5.1, J1.2, R4.1, SW1.1, SW1.2, SW1.3, SW1.4, SW1.5, SW1.6, SW1.7, SW1.8, U1.11 (GND), U1.32 (GND), U1.62 (GND), U1.81 (GND), U1.99 (GND), Y1.2; also elsewhere on the board
GPS_CTRL: U1.70 (PG2); also elsewhere on the board
GPS_RX: U1.63 (PJ0); also elsewhere on the board
GPS_TX: U1.64 (PJ1); also elsewhere on the board
HOA: U1.42 (PL7); also elsewhere on the board
HOB: U1.40 (PL5); also elsewhere on the board
HOC: U1.39 (PL4); also elsewhere on the board
HOD: U1.41 (PL6); also elsewhere on the board
HTA: U1.38 (PL3); also elsewhere on the board
HTB: U1.36 (PL1); also elsewhere on the board
HTC: U1.35 (PL0); also elsewhere on the board
HTD: U1.37 (PL2); also elsewhere on the board
MISO: U1.22 (PB3); also elsewhere on the board
MOA: U1.60 (PC7); also elsewhere on the board
MOB: U1.58 (PC5); also elsewhere on the board
MOC: U1.57 (PC4); also elsewhere on the board
MOD: U1.59 (PC6); also elsewhere on the board
MOSI: U1.21 (PB2); also elsewhere on the board
MTA: U1.56 (PC3); also elsewhere on the board
MTB: U1.54 (PC1); also elsewhere on the board
MTC: U1.53 (PC0); also elsewhere on the board
MTD: U1.55 (PC2); also elsewhere on the board
unnamed: R2.1, U1.34 (XTAL1), Y1.1
unnamed: R2.2, U1.33 (XTAL2), Y1.3
RST: C1.2, J1.1, R1.2, U1.30 (~RESET); also elsewhere on the board
RTC_INT: U1.6 (PE4); also elsewhere on the board
RXI: U1.3 (PE1); also elsewhere on the board
SCK: U1.20 (PB1); also elsewhere on the board
TXO: U1.2 (PE0); also elsewhere on the board

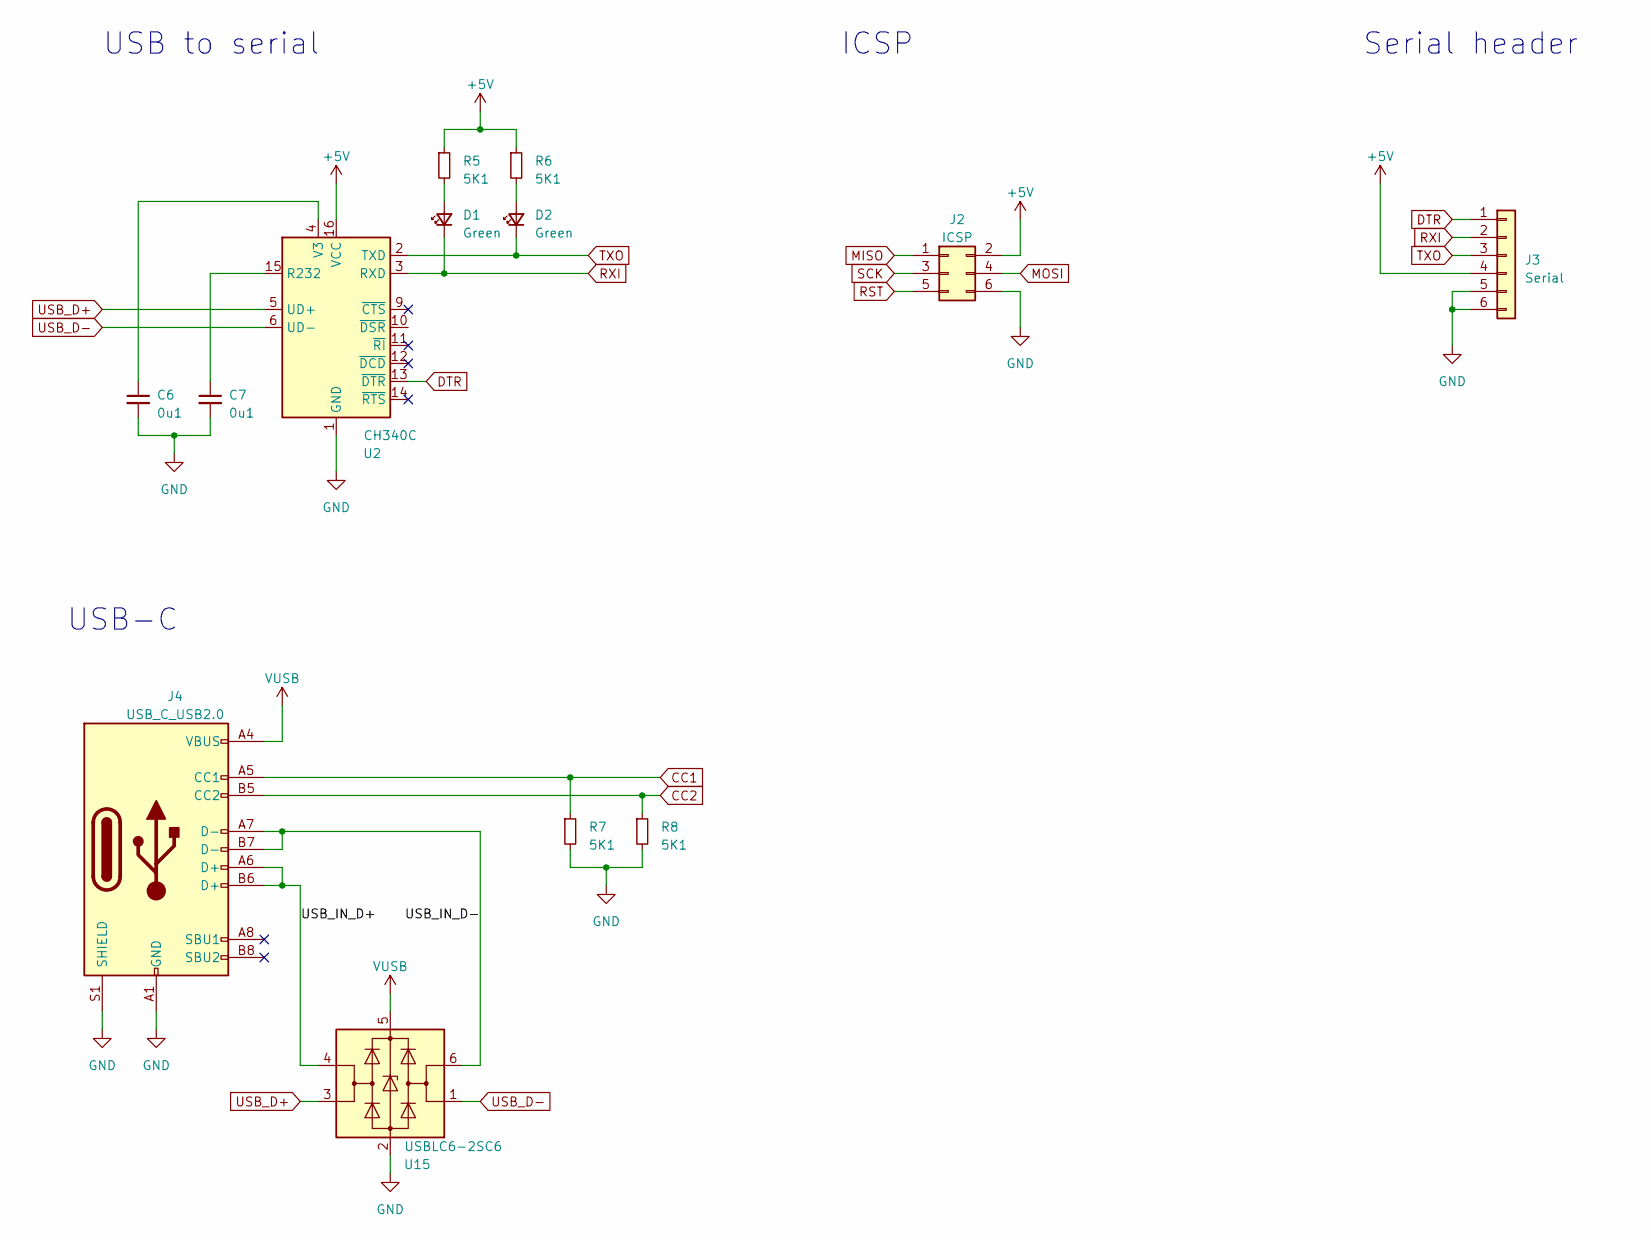
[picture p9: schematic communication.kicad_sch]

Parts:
C6, C7: 0u1; C_0603_1608Metric
D1, D2: Green; LED_0603_1608Metric
J2: ICSP; PinSocket_2x03_P2.54mm_Vertical
J3: Serial; PinSocket_1x06_P2.54mm_Vertical
J4: USB_C_USB2.0; USB_C_Receptacle_HRO_TYPE-C-31-M-12
R5, R6, R7, R8: 5K1; R_0603_1608Metric
U2: CH340C; SOIC-16_3.9x9.9mm_P1.27mm
U15: USBLC6-2SC6; SOT-23-6

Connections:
+5V: J2.2, J3.4, R5.1, R6.1, U2.16 (VCC); also elsewhere on the board
/Communication/USB_IN_D+: J4.A6 (D+), J4.B6 (D+), U15.4 (I/O2)
/Communication/USB_IN_D-: J4.A7 (D-), J4.B7 (D-), U15.6 (I/O1)
CC1: J4.A5 (CC1), R7.1; also elsewhere on the board
CC2: J4.B5 (CC2), R8.1; also elsewhere on the board
DTR: J3.1, U2.13 (~DTR); also elsewhere on the board
GND: C6.2, C7.2, J2.6, J3.5, J3.6, J4.A1 (GND), J4.A12 (GND), J4.B1 (GND), J4.B12 (GND), J4.S1 (SHIELD), R7.2, R8.2, U2.1 (GND), U15.2 (GND); also elsewhere on the board
MISO: J2.1; also elsewhere on the board
MOSI: J2.4; also elsewhere on the board
unnamed: C6.1, U2.4 (V3)
unnamed: C7.1, U2.15 (R232)
unnamed: D1.2 (A), R5.2
unnamed: D2.2 (A), R6.2
RST: J2.5; also elsewhere on the board
RXI: D1.1 (K), J3.2, U2.3 (RXD); also elsewhere on the board
SCK: J2.3; also elsewhere on the board
TXO: D2.1 (K), J3.3, U2.2 (TXD); also elsewhere on the board
USB_D+: U2.5 (UD+), U15.3 (I/O2)
USB_D-: U2.6 (UD-), U15.1 (I/O1)
VUSB: J4.A4 (VBUS), J4.A9 (VBUS), J4.B4 (VBUS), J4.B9 (VBUS), U15.5 (VBUS); also elsewhere on the board

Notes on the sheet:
USB-C
USB to serial
ICSP
Serial header

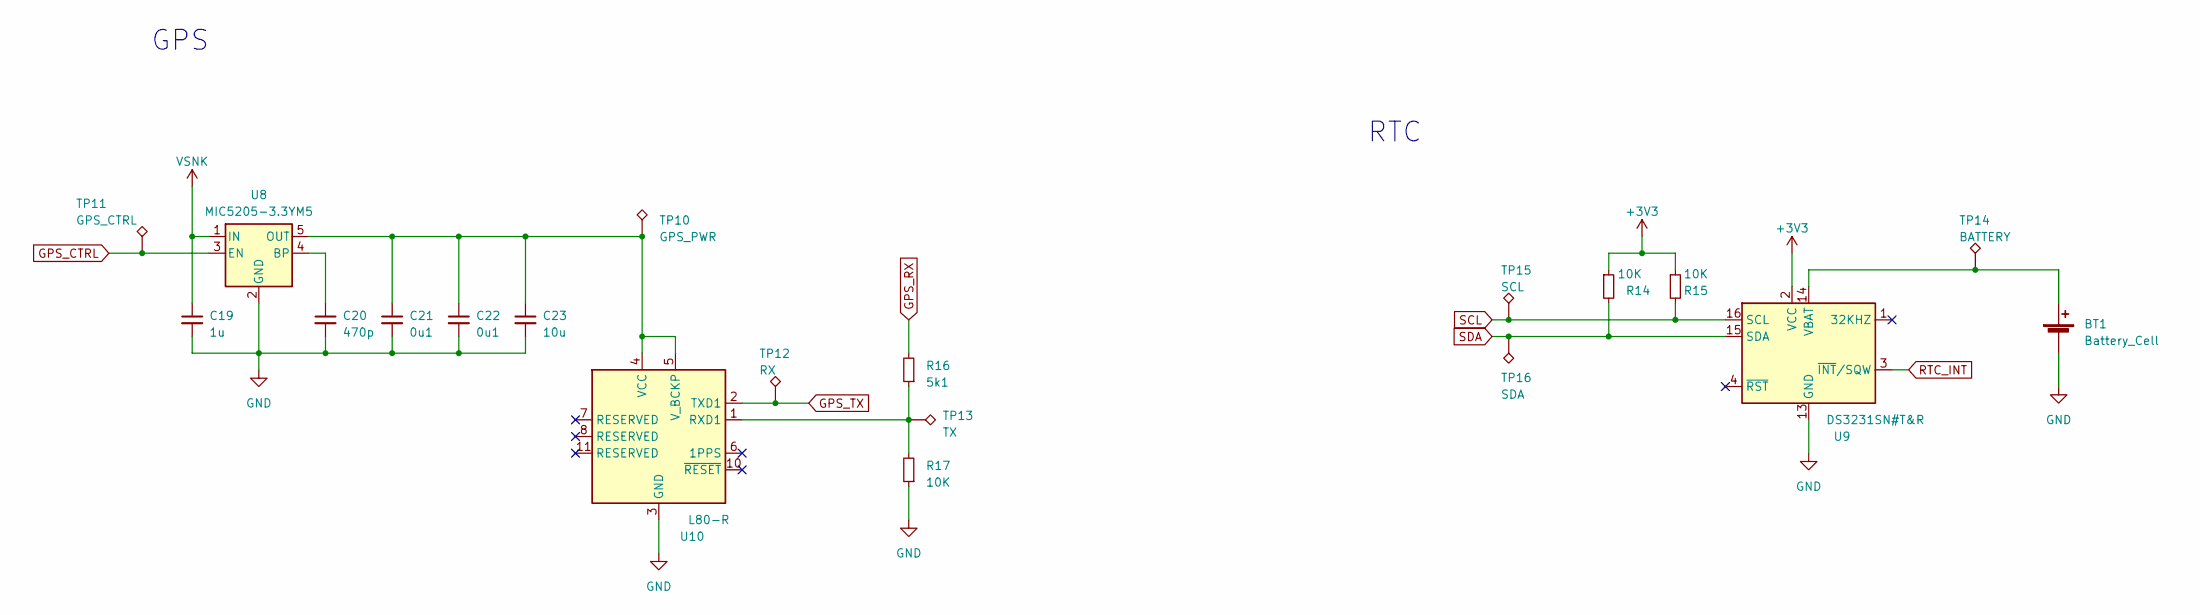
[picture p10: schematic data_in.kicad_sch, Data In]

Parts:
BT1: Battery_Cell; BatteryHolder_LINX_BAT-HLD-012-SMT
C19: 1u; C_0603_1608Metric
C20: 470p; C_0603_1608Metric
C21, C22: 0u1; C_0603_1608Metric
C23: 10u; C_0603_1608Metric
R14, R15, R17: 10K; R_0603_1608Metric
R16: 5k1; R_0603_1608Metric
TP10: GPS_PWR; TestPoint_THTPad_D2.0mm_Drill0.9mm
TP11: GPS_CTRL; TestPoint_THTPad_D2.0mm_Drill0.9mm
TP12: RX; TestPoint_THTPad_D2.0mm_Drill0.9mm
TP13: TX; TestPoint_THTPad_D2.0mm_Drill0.9mm
TP14: BATTERY; TestPoint_THTPad_D2.0mm_Drill0.9mm
TP15: SCL; TestPoint_THTPad_D2.0mm_Drill0.9mm
TP16: SDA; TestPoint_THTPad_D2.0mm_Drill0.9mm
U8: MIC5205-3.3YM5; SOT-23-5
U9: DS3231SN#T&R; SOIC-16W_7.5x10.3mm_P1.27mm
U10: L80-R; Quectel_L80-R

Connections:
+3V3: R14.1, R15.1, U9.2 (VCC); also elsewhere on the board
GND: BT1.2 (-), C19.2, C20.2, C21.2, C22.2, C23.2, R17.1, U8.2 (GND), U9.5 (GND), U9.6 (GND), U9.7 (GND), U9.8 (GND), U9.9 (GND), U9.10 (GND), U9.11 (GND), U9.12 (GND), U9.13 (GND), U10.3 (GND), U10.12 (GND); also elsewhere on the board
GPS_CTRL: TP11.1, U8.3 (EN); also elsewhere on the board
GPS_RX: R16.2; also elsewhere on the board
GPS_TX: TP12.1, U10.2 (TXD1); also elsewhere on the board
unnamed: BT1.1 (+), TP14.1, U9.14 (VBAT)
unnamed: C20.1, U8.4 (BP)
unnamed: C21.1, C22.1, C23.1, TP10.1, U8.5 (OUT), U10.4 (VCC), U10.5 (V_BCKP)
unnamed: R16.1, R17.2, TP13.1, U10.1 (RXD1)
RTC_INT: U9.3 (~INT~/SQW); also elsewhere on the board
SCL: R15.2, TP15.1, U9.16 (SCL)
SDA: R14.2, TP16.1, U9.15 (SDA)
VSNK: C19.1, U8.1 (IN); also elsewhere on the board

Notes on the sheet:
GPS
RTC

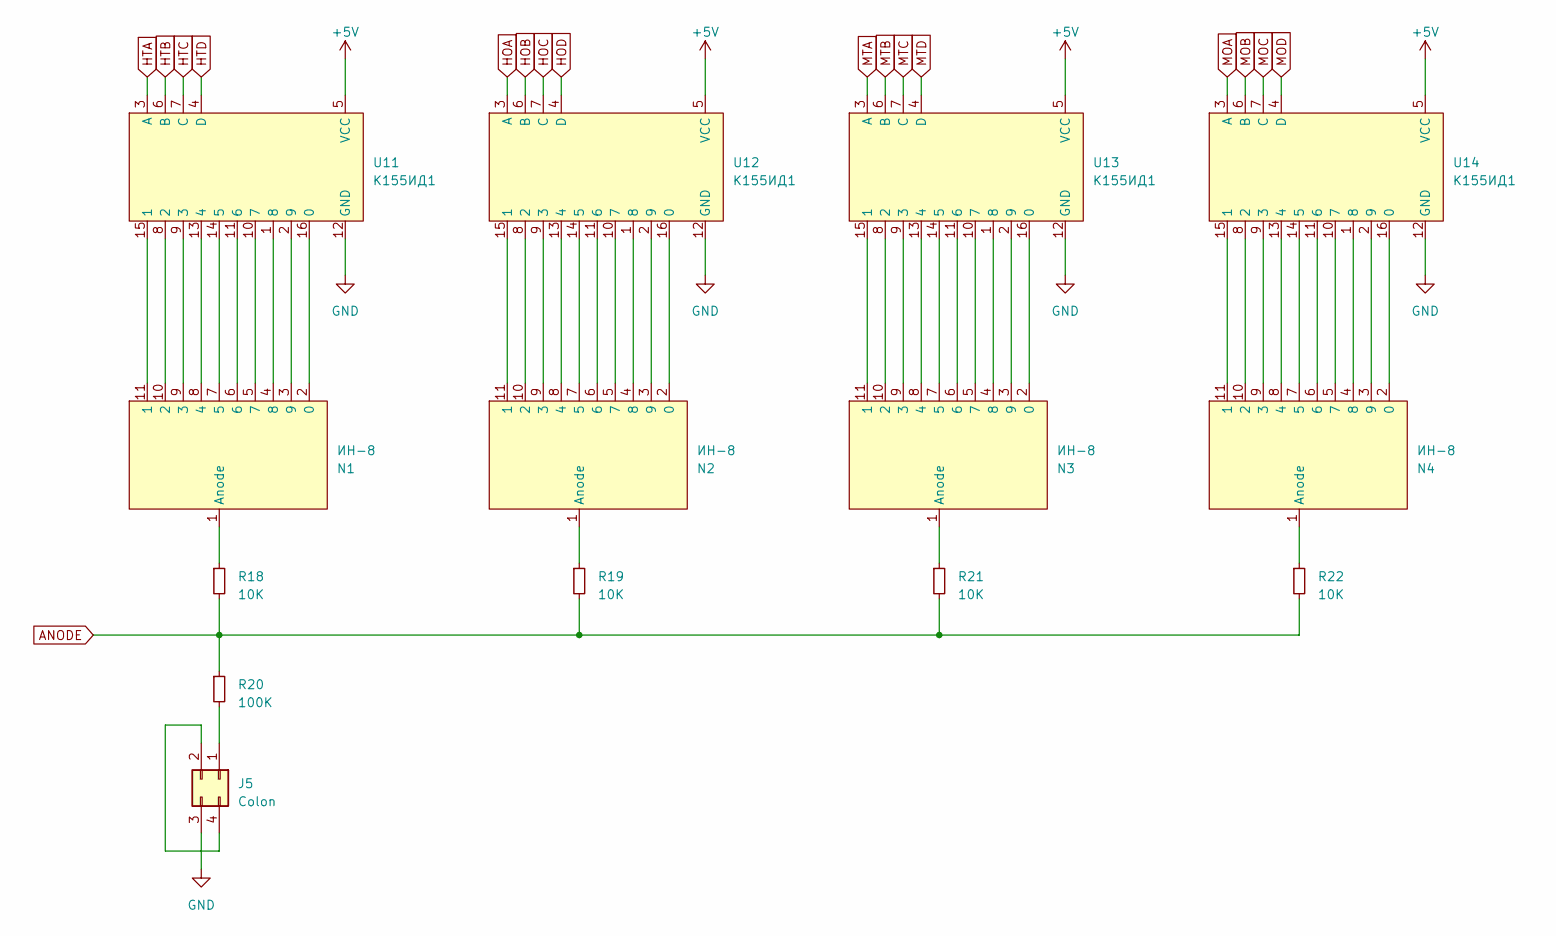
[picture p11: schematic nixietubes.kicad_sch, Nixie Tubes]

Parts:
J5: Colon; PinSocket_2x02_P2.54mm_Vertical
N1, N2, N3, N4: ИН-8
R18, R19, R21, R22: 10K; R_0805_2012Metric
R20: 100K; R_0603_1608Metric
U11, U12, U13, U14: К155ИД1; DIP-16_W7.62mm

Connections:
+5V: U11.5 (VCC), U12.5 (VCC), U13.5 (VCC), U14.5 (VCC); also elsewhere on the board
ANODE: R18.2, R19.2, R20.1, R21.2, R22.2; also elsewhere on the board
GND: J5.3, U11.12 (GND), U12.12 (GND), U13.12 (GND), U14.12 (GND); also elsewhere on the board
HOA: U12.3 (A); also elsewhere on the board
HOB: U12.6 (B); also elsewhere on the board
HOC: U12.7 (C); also elsewhere on the board
HOD: U12.4 (D); also elsewhere on the board
HTA: U11.3 (A); also elsewhere on the board
HTB: U11.6 (B); also elsewhere on the board
HTC: U11.7 (C); also elsewhere on the board
HTD: U11.4 (D); also elsewhere on the board
MOA: U14.3 (A); also elsewhere on the board
MOB: U14.6 (B); also elsewhere on the board
MOC: U14.7 (C); also elsewhere on the board
MOD: U14.4 (D); also elsewhere on the board
MTA: U13.3 (A); also elsewhere on the board
MTB: U13.6 (B); also elsewhere on the board
MTC: U13.7 (C); also elsewhere on the board
MTD: U13.4 (D); also elsewhere on the board
unnamed: J5.1, R20.2
unnamed: J5.2, J5.4
unnamed: N1.1 (Anode), R18.1
unnamed: N1.2 (0), U11.16 (0)
unnamed: N1.3 (9), U11.2 (9)
unnamed: N1.4 (8), U11.1 (8)
unnamed: N1.5 (7), U11.10 (7)
unnamed: N1.6, U11.11 (6)
unnamed: N1.7 (5), U11.14 (5)
unnamed: N1.8 (4), U11.13 (4)
unnamed: N1.9 (3), U11.9 (3)
unnamed: N1.10 (2), U11.8 (2)
unnamed: N1.11 (1), U11.15 (1)
unnamed: N2.1 (Anode), R19.1
unnamed: N2.2 (0), U12.16 (0)
unnamed: N2.3 (9), U12.2 (9)
unnamed: N2.4 (8), U12.1 (8)
unnamed: N2.5 (7), U12.10 (7)
unnamed: N2.6, U12.11 (6)
unnamed: N2.7 (5), U12.14 (5)
unnamed: N2.8 (4), U12.13 (4)
unnamed: N2.9 (3), U12.9 (3)
unnamed: N2.10 (2), U12.8 (2)
unnamed: N2.11 (1), U12.15 (1)
unnamed: N3.1 (Anode), R21.1
unnamed: N3.2 (0), U13.16 (0)
unnamed: N3.3 (9), U13.2 (9)
unnamed: N3.4 (8), U13.1 (8)
unnamed: N3.5 (7), U13.10 (7)
unnamed: N3.6, U13.11 (6)
unnamed: N3.7 (5), U13.14 (5)
unnamed: N3.8 (4), U13.13 (4)
unnamed: N3.9 (3), U13.9 (3)
unnamed: N3.10 (2), U13.8 (2)
unnamed: N3.11 (1), U13.15 (1)
unnamed: N4.1 (Anode), R22.1
unnamed: N4.2 (0), U14.16 (0)
unnamed: N4.3 (9), U14.2 (9)
unnamed: N4.4 (8), U14.1 (8)
unnamed: N4.5 (7), U14.10 (7)
unnamed: N4.6, U14.11 (6)
unnamed: N4.7 (5), U14.14 (5)
unnamed: N4.8 (4), U14.13 (4)
unnamed: N4.9 (3), U14.9 (3)
unnamed: N4.10 (2), U14.8 (2)
unnamed: N4.11 (1), U14.15 (1)

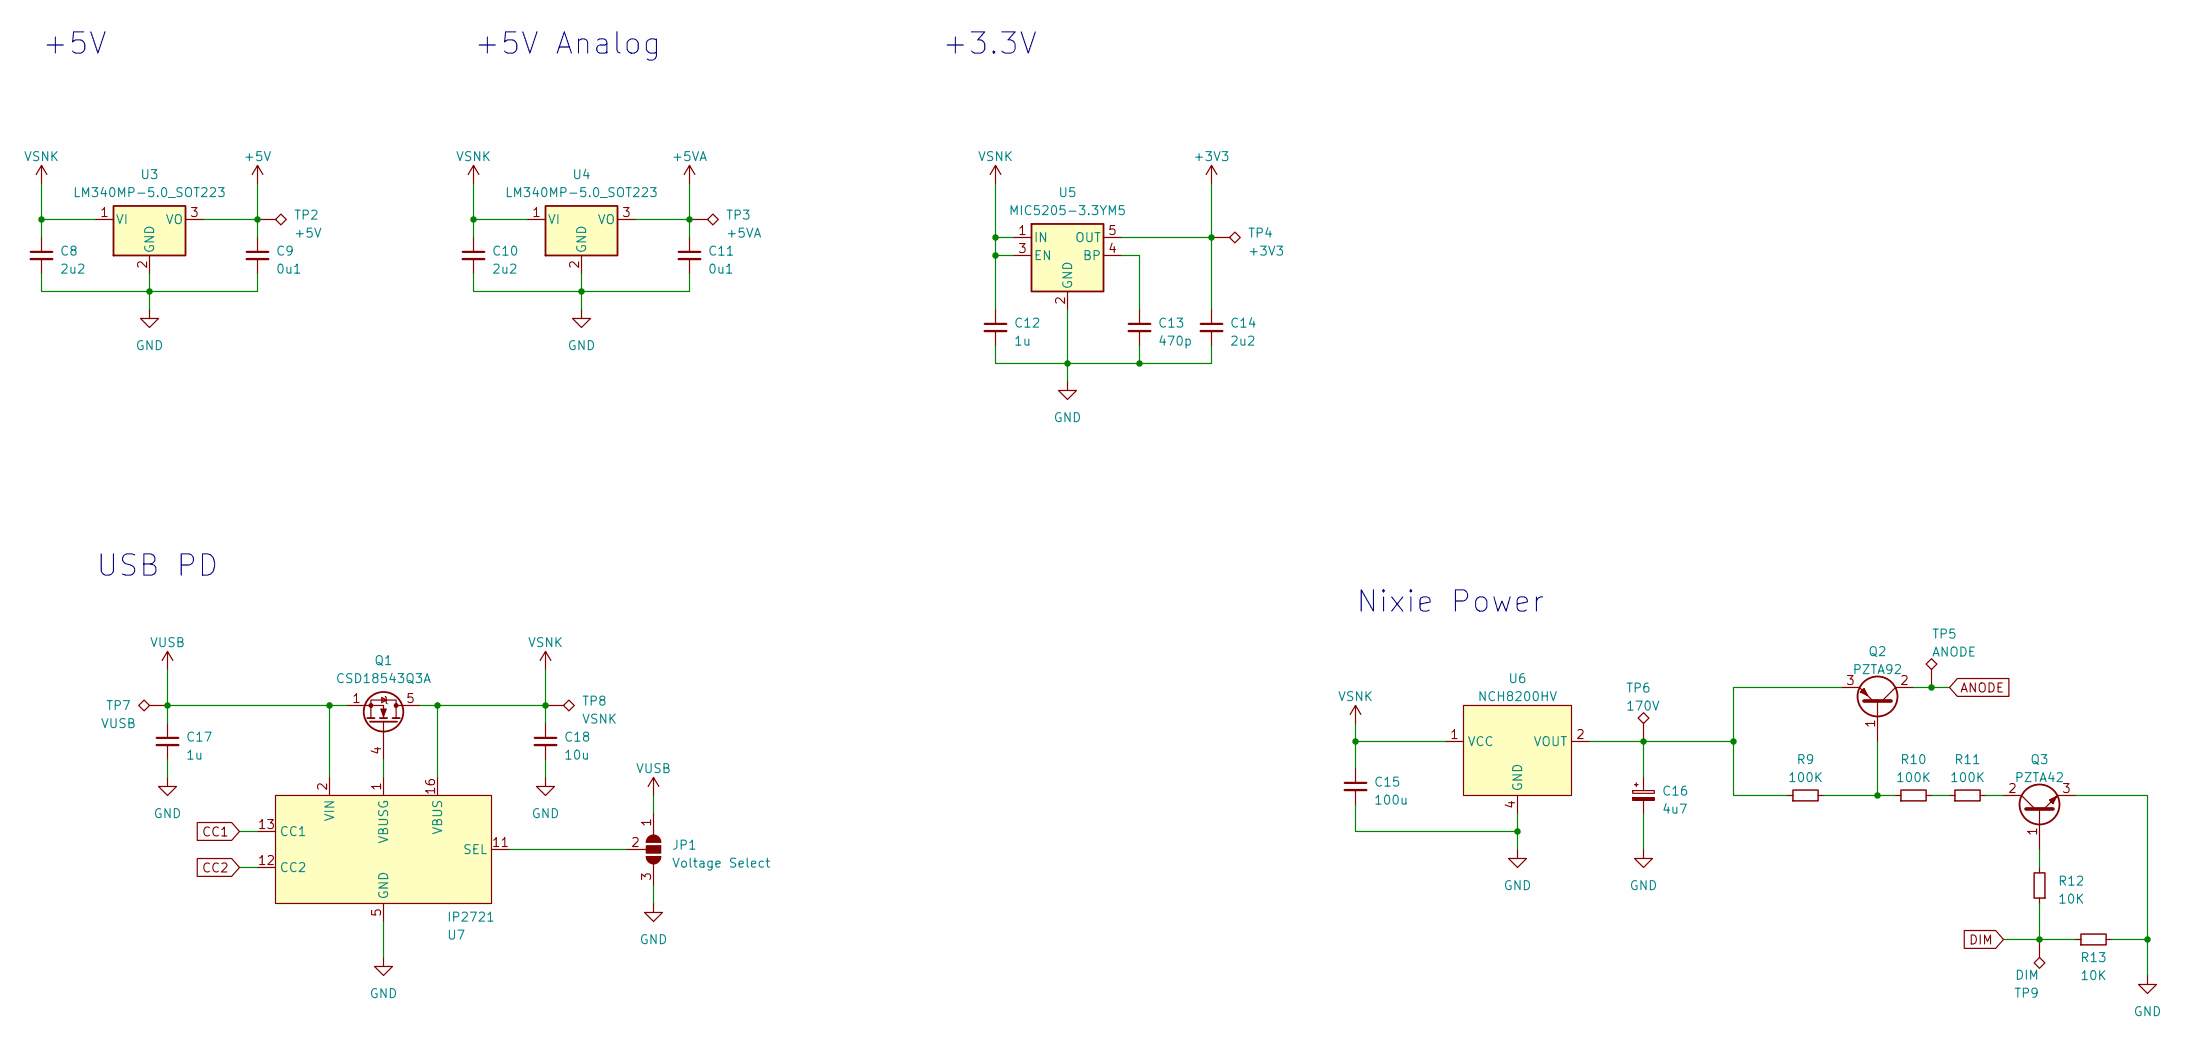
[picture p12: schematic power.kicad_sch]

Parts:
C8, C10, C14: 2u2; C_0603_1608Metric
C9, C11: 0u1; C_0603_1608Metric
C12, C17: 1u; C_0603_1608Metric
C13: 470p; C_0603_1608Metric
C15: 100u; C_0805_2012Metric
C16: 4u7; CP_Radial_D8.0mm_P3.50mm
C18: 10u; C_0603_1608Metric
JP1: Voltage Select; SolderJumper-3_P1.3mm_Open_Pad1.0x1.5mm
Q1: CSD18543Q3A; VSON-8_3.3x3.3mm_P0.65mm_NexFET
Q2: PZTA92; SOT-223-3_TabPin2
Q3: PZTA42; SOT-223-3_TabPin2
R9, R10, R11: 100K; R_0603_1608Metric
R12, R13: 10K; R_0603_1608Metric
TP2: +5V; TestPoint_THTPad_D2.0mm_Drill0.9mm
TP3: +5VA; TestPoint_THTPad_D2.0mm_Drill0.9mm
TP4: +3V3; TestPoint_THTPad_D2.0mm_Drill0.9mm
TP5: ANODE; TestPoint_THTPad_D2.0mm_Drill0.9mm
TP6: 170V; TestPoint_THTPad_D2.0mm_Drill0.9mm
TP7: VUSB; TestPoint_THTPad_D2.0mm_Drill0.9mm
TP8: VSNK; TestPoint_THTPad_D2.0mm_Drill0.9mm
TP9: DIM; TestPoint_THTPad_D2.0mm_Drill0.9mm
U3, U4: LM340MP-5.0_SOT223; SOT-223-3_TabPin2
U5: MIC5205-3.3YM5; SOT-23-5
U6: NCH8200HV
U7: IP2721; TSSOP-16-1EP_4.4x5mm_P0.65mm_EP3x3mm_ThermalVias

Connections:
+3V3: C14.1, TP4.1, U5.5 (OUT); also elsewhere on the board
+5V: C9.1, TP2.1, U3.3 (VO); also elsewhere on the board
+5VA: C11.1, TP3.1, U4.3 (VO); also elsewhere on the board
ANODE: Q2.2 (C), TP5.1; also elsewhere on the board
CC1: U7.13 (CC1); also elsewhere on the board
CC2: U7.12 (CC2); also elsewhere on the board
DIM: R12.1, R13.1, TP9.1; also elsewhere on the board
GND: C8.2, C9.2, C10.2, C11.2, C12.2, C13.2, C14.2, C15.2, C16.2, C17.2, C18.2, JP1.3 (B), Q3.3 (E), R13.2, U3.2 (GND), U4.2 (GND), U5.2 (GND), U6.3 (GND), U6.4 (GND), U7.5 (GND); also elsewhere on the board
unnamed: C13.1, U5.4 (BP)
unnamed: C16.1, Q2.3 (E), R9.1, TP6.1, U6.2 (VOUT)
unnamed: JP1.2 (C), U7.11 (SEL)
unnamed: Q1.4 (G), U7.1 (VBUSG)
unnamed: Q2.1 (B), R9.2, R10.1
unnamed: Q3.1 (B), R12.2
unnamed: Q3.2 (C), R11.2
unnamed: R10.2, R11.1
VSNK: C8.1, C10.1, C12.1, C15.1, C18.1, Q1.5 (D), TP8.1, U3.1 (VI), U4.1 (VI), U5.1 (IN), U5.3 (EN), U6.1 (VCC), U7.16 (VBUS); also elsewhere on the board
VUSB: C17.1, JP1.1 (A), Q1.1 (S), Q1.2 (S), Q1.3 (S), TP7.1, U7.2 (VIN); also elsewhere on the board

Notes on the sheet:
+5V
USB PD
+5V Analog
+3.3V
Nixie Power


Board: 2 copper layers, 115.0 x 80.0 mm, 102 parts (1 on the bottom side), 117 nets.

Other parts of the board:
C3#2, C4#2, C5#2: 0u1; C_0603_1608Metric

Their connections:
GND: C3#2.2, C4#2.2, C5#2.2; also elsewhere on the board
unnamed: C3#2.1, C4#2.1, C5#2.1

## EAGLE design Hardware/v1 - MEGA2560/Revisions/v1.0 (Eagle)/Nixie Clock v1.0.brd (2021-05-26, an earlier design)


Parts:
C1, C2, C3, C4: 0.1uF; C0603
R1: 10K; R0603
R2: 1M; R0603
U1: ATMEGA2560AU; TQFP100; MPN ATMEGA2560-16AU
X1: CSTCR6M00G53Z; CSTCR6M; MPN CSTCE16M0V13C99-R0

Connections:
+5V: C2.1, C3.1, C4.1, R1.2, U1.10 (VCC), U1.31 (VCC1), U1.61 (VCC2), U1.80 (VCC3); also elsewhere on the board
DIM: U1.1 ((OC0B)PG5); also elsewhere on the board
DST: U1.71 ((AD7)PA7); also elsewhere on the board
DTR: C1.1; also elsewhere on the board
EIGHT: U1.74 ((AD4)PA4); also elsewhere on the board
EXTRA1: U1.78 ((AD0)PA0); also elsewhere on the board
FOUR: U1.75 ((AD3)PA3); also elsewhere on the board
GND: C2.2, C3.2, C4.2, U1.11 (GND), U1.32 (GND1), U1.62 (GND2), U1.81 (GND3), U1.99 (AGND), X1.2; also elsewhere on the board
GPS_CTRL: U1.70 ((ALE)PG2); also elsewhere on the board
GPS_RX: U1.64 (PJ1(TXD3/PCINT10)); also elsewhere on the board
GPS_TX: U1.63 (PJ0(RXD3/PCINT9)); also elsewhere on the board
HOA: U1.42 (PL7); also elsewhere on the board
HOB: U1.40 (PL5(OC5C)); also elsewhere on the board
HOC: U1.39 (PL4(OC5B)); also elsewhere on the board
HOD: U1.41 (PL6); also elsewhere on the board
HTA: U1.38 (PL3(OC5A)); also elsewhere on the board
HTB: U1.36 (PL1(ICP5)); also elsewhere on the board
HTC: U1.35 (PL0(ICP4)); also elsewhere on the board
HTD: U1.37 (PL2(T5)); also elsewhere on the board
LIGHT: U1.97 ((ADC0)PF0); also elsewhere on the board
MISO: U1.22 ((MISO/PCINT3)PB3); also elsewhere on the board
MOA: U1.60 ((A15)PC7); also elsewhere on the board
MOB: U1.58 ((A13)PC5); also elsewhere on the board
MOC: U1.57 ((A12)PC4); also elsewhere on the board
MOD: U1.59 ((A14)PC6); also elsewhere on the board
MOSI: U1.21 ((MOSI/PCINT2)PB2); also elsewhere on the board
MTA: U1.56 ((A11)PC3); also elsewhere on the board
MTB: U1.54 ((A9)PC1); also elsewhere on the board
MTC: U1.53 ((A8)PC0); also elsewhere on the board
MTD: U1.55 ((A10)PC2); also elsewhere on the board
unnamed: R2.2, U1.34 (XTAL1), X1.3
unnamed: R2.1, U1.33 (XTAL2), X1.1
ONE: U1.77 ((AD1)PA1); also elsewhere on the board
PLUS_MINUS: U1.73 ((AD5)PA5); also elsewhere on the board
RST: C1.2, R1.1, U1.30 (RESET); also elsewhere on the board
RTC_INT: U1.6 ((OC3B/INT4)PE4); also elsewhere on the board
RXI: U1.3 ((TXD0)PE1); also elsewhere on the board
SCK: U1.20 ((SCK/PCINT1)PB1); also elsewhere on the board
SCL: U1.43 ((SCL/INT0)PD0); also elsewhere on the board
SDA: U1.44 ((SDA/INT1)PD1); also elsewhere on the board
TIME_MODE: U1.72 ((AD6)PA6); also elsewhere on the board
TWO: U1.76 ((AD2)PA2); also elsewhere on the board
TXO: U1.2 ((RXD0/PCIN8)PE0); also elsewhere on the board
VCCA: U1.98 (AREF), U1.100 (AVCC); also elsewhere on the board

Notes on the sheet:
Miccrocontroller
1.0


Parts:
C5: 10uF; C0603
C6: 0.1uF; C0603
D1, D2: LEDCHIP-LED0603; CHIP-LED0603
J1: 6_PIN_SERIAL_TARGETSILK; 6_PIN_SERIAL_TARGET_SIDE_W_SILK
J2: ISCP; 2X3
J5: HRO_TYPE-C-31-M-12
R3, R4, R5, R6: 10K; R0603
U2: CH340C; SO016; MPN CH340C

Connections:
+5V: J1.P$4 (VCC), J2.2, R3.2, R4.2, R5.2, R6.1, U2.16 (VCC); also elsewhere on the board
CC1: J5.A5 (CC1); also elsewhere on the board
CC2: J5.B5 (CC2); also elsewhere on the board
D+: J5.A7 (DN1), J5.B7 (DN2), U2.5 (UD+)
D-: J5.A6 (DP1), J5.B6 (DP2), U2.6 (UD-)
DTR: J1.P$1 (DTR), U2.13 (!DTR); also elsewhere on the board
GND: C5.2, C6.2, J1.P$5 (CTS), J1.P$6 (GND), J2.6, J5.A1B12 (GND), J5.B1A12 (GND), J5.S1 (SHIELD), J5.S2 (SHIELD), J5.S3 (SHIELD), J5.S4 (SHIELD), U2.1 (GND); also elsewhere on the board
MISO: J2.1; also elsewhere on the board
MOSI: J2.4; also elsewhere on the board
unnamed: C5.1, U2.15 (R232)
unnamed: C6.1, U2.4 (V3)
unnamed: D1.A, R3.1, R4.1
unnamed: D2.A, R5.1, R6.2
RST: J2.5; also elsewhere on the board
RXI: D1.C, J1.P$3 (RXI), U2.3 (RXI); also elsewhere on the board
SCK: J2.3; also elsewhere on the board
TXO: D2.C, J1.P$2 (TXO), U2.2 (TXO); also elsewhere on the board
V_USB: J5.A4B9 (VBUS), J5.B4A9 (VBUS); also elsewhere on the board

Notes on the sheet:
USB to Serial
Comunication
1.0
ISCP
Serial header


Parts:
3V3, 5V, 5V_ANALOG, 170V: TPPAD1-13; P1-13
C7, C8, C15: 1uF; C0603
C13: 100uF; C0603
C14: 4.7uF; E3,5-8
C16: 10uF; C0603
C17, C18: 0.22uF; C0603
DIM: TPPAD1-13; P1-13
R7, R8, R9: 100K; R0603
R10, R11: 10K; R0603
SJ1: SJ2W; SJ_2
T1: PZTA92; SOT223
T2: PZTA42; SOT223
T3: CSD18543Q3A; VSONP-8
U7: NCH8200HV
U9: MIC5504-3.3YM5TR; SOT95P280X130-5N; MPN MIC5504-3.3YM5-TR
U12: IP2721; TSSOP16EXP
U13: LM340MP-05; SOT223; MPN LM340MP-5.0/NOPB
U14: LM340MP-05; SOT223
VOUT: TPPAD1-13; P1-13
V_USB: TPPAD1-13; P1-13

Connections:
+3V3: 3V3.TP, C7.1, U9.5 (OUT); also elsewhere on the board
+5V: 5V.TP, C8.1, U9.1 (IN), U9.3 (EN), U13.3 (VO); also elsewhere on the board
ANODE: T1.2 (C), T1.4 (C); also elsewhere on the board
CC1: U12.13 (CC1); also elsewhere on the board
CC2: U12.12 (CC2); also elsewhere on the board
DIM: DIM.TP, R10.2, R11.1; also elsewhere on the board
GND: C7.2, C8.2, C13.2, C14.-, C15.2, C16.2, C17.2, C18.2, R11.2, SJ1.3, T2.3 (E), U7.3 (GND), U7.4 (GND), U9.2 (GND), U12.5 (GND), U12.EXP (GND), U13.4 (GND), U14.4 (GND); also elsewhere on the board
unnamed: T3.4 (G), U12.1 (VBUSG)
unnamed: SJ1.2, U12.11 (SEL)
unnamed: R10.1, T2.1 (B)
unnamed: 170V.TP, C14.+, R7.2, T1.3 (E), U7.2 (VOUT)
unnamed: R7.1, R8.1, T1.1 (B)
unnamed: R9.2, T2.2 (C), T2.4 (C)
unnamed: R8.2, R9.1
VCCA: 5V_ANALOG.TP, U14.3 (VO); also elsewhere on the board
VOUT: C13.1, C16.1, C17.1, C18.1, T3.5 (D), T3.6 (D), T3.7 (D), T3.8 (D), T3.9 (D), T3.10 (D), T3.11 (D), T3.12 (D), U7.1 (VCC), U12.16 (VBUS), U13.1 (VI), U14.1 (VI), VOUT.TP
V_USB: C15.1, SJ1.1, T3.1 (S), T3.2 (S), T3.3 (S), U12.2 (VIN), V_USB.TP; also elsewhere on the board

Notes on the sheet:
Nixie Power
3.3V
Power
1.0
USB PD
5V Analog


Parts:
BATTERY: TPPAD1-13; P1-13
BT1: CR1220; CH291-1220LF
C9, C12: 10uF; C0603
C10, C11: 0.1uF; C0603
GPS_CTRL: TPPAD1-13; P1-13
GPS_PWR: TPPAD1-13; P1-13
LIGHT: TPPAD1-13; P1-13
PH1: VT20N1; TO46-VT200
R17, R18, R19, R20, R21, R22: 10K; R0603
RTC_INT: TPPAD1-13; P1-13
RX: TPPAD1-13; P1-13
S1: SW_DIP-8; EDG-08
SCL: TPPAD1-13; P1-13
SDA: TPPAD1-13; P1-13
TX: TPPAD1-13; P1-13
U8: DS3231SN#T&R; SOIC127P1032X265-16N
U10: MIC5504-3.3YM5TR; SOT95P280X130-5N; MPN MIC5504-3.3YM5-TR
U11: L80; XCVR_L80

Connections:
+3V3: R17.2, R18.2, U8.2 (VCC); also elsewhere on the board
+5V: U10.1 (IN); also elsewhere on the board
DST: S1.16; also elsewhere on the board
EIGHT: S1.13; also elsewhere on the board
EXTRA1: S1.9; also elsewhere on the board
FOUR: S1.12; also elsewhere on the board
GND: BT1.-, C9.2, C10.2, C11.2, C12.2, R20.1, R22.1, S1.1, S1.2, S1.3, S1.4, S1.5, S1.6, S1.7, S1.8, U8.13 (GND), U10.2 (GND), U11.3 (GND), U11.12 (GND); also elsewhere on the board
GPS_CTRL: GPS_CTRL.TP, U10.3 (EN); also elsewhere on the board
GPS_RX: R19.1; also elsewhere on the board
GPS_TX: TX.TP, U11.2 (TXD1); also elsewhere on the board
LIGHT: C12.1, LIGHT.TP, PH1.2, R22.2; also elsewhere on the board
unnamed: BATTERY.TP, BT1.+, U8.14 (VBAT)
unnamed: C9.1, C10.1, C11.1, GPS_PWR.TP, U10.5 (OUT), U11.4 (VCC), U11.5 (V_BCKP)
unnamed: R19.2, R21.2, RX.TP, U11.1 (RXD1)
unnamed: R20.2, R21.1
ONE: S1.10; also elsewhere on the board
PLUS_MINUS: S1.14; also elsewhere on the board
RTC_INT: RTC_INT.TP, U8.3 (SQW/!INT); also elsewhere on the board
SCL: R18.1, SCL.TP, U8.16 (SCL); also elsewhere on the board
SDA: R17.1, SDA.TP, U8.15 (SDA); also elsewhere on the board
TIME_MODE: S1.15; also elsewhere on the board
TWO: S1.11; also elsewhere on the board
VCCA: PH1.1; also elsewhere on the board

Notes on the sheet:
RTC
GPS
RTC and GPS
1.0
Settings
Photoresistor


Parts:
ANODE: TPPAD1-13; P1-13
J3, J4: CONN_02LOCK_LONGPADS; 1X02_LOCK_LONGPADS
N1, N2, N3, N4: ИН-8; IN-8_SOCKET
R12, R13, R14, R15: 10k; M0805
R16: 100k; R0603
U3, U4, U5, U6: K155ID1; DIL16-KIT

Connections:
+5V: U3.5 (VCC), U4.5 (VCC), U5.5 (VCC), U6.5 (VCC); also elsewhere on the board
ANODE: ANODE.TP, R12.1, R13.1, R14.1, R15.1, R16.1; also elsewhere on the board
GND: J4.1, U3.12 (GND), U4.12 (GND), U5.12 (GND), U6.12 (GND); also elsewhere on the board
HOA: U4.3 (A); also elsewhere on the board
HOB: U4.6 (B); also elsewhere on the board
HOC: U4.7 (C); also elsewhere on the board
HOD: U4.4 (D); also elsewhere on the board
HTA: U3.3 (A); also elsewhere on the board
HTB: U3.6 (B); also elsewhere on the board
HTC: U3.7 (C); also elsewhere on the board
HTD: U3.4 (D); also elsewhere on the board
MOA: U6.3 (A); also elsewhere on the board
MOB: U6.6 (B); also elsewhere on the board
MOC: U6.7 (C); also elsewhere on the board
MOD: U6.4 (D); also elsewhere on the board
MTA: U5.3 (A); also elsewhere on the board
MTB: U5.6 (B); also elsewhere on the board
MTC: U5.7 (C); also elsewhere on the board
MTD: U5.4 (D); also elsewhere on the board
unnamed: J3.1, R16.2
unnamed: J3.2, J4.2
unnamed: N1.9, U3.2 (9)
unnamed: N1.8, U3.1 (8)
unnamed: N1.7, U3.10 (7)
unnamed: N1.6, U3.11 (6)
unnamed: N1.5, U3.14 (5)
unnamed: N1.4, U3.13 (4)
unnamed: N1.3, U3.9 (3)
unnamed: N1.2, U3.8 (2)
unnamed: N1.1, U3.15 (1)
unnamed: N1.0, U3.16 (0)
unnamed: N1.A, R12.2
unnamed: N2.9, U4.2 (9)
unnamed: N2.8, U4.1 (8)
unnamed: N2.7, U4.10 (7)
unnamed: N2.6, U4.11 (6)
unnamed: N2.5, U4.14 (5)
unnamed: N2.4, U4.13 (4)
unnamed: N2.3, U4.9 (3)
unnamed: N2.2, U4.8 (2)
unnamed: N2.1, U4.15 (1)
unnamed: N2.0, U4.16 (0)
unnamed: N2.A, R13.2
unnamed: N3.9, U5.2 (9)
unnamed: N3.8, U5.1 (8)
unnamed: N3.7, U5.10 (7)
unnamed: N3.6, U5.11 (6)
unnamed: N3.5, U5.14 (5)
unnamed: N3.4, U5.13 (4)
unnamed: N3.3, U5.9 (3)
unnamed: N3.2, U5.8 (2)
unnamed: N3.1, U5.15 (1)
unnamed: N3.0, U5.16 (0)
unnamed: N3.A, R14.2
unnamed: N4.9, U6.2 (9)
unnamed: N4.8, U6.1 (8)
unnamed: N4.7, U6.10 (7)
unnamed: N4.6, U6.11 (6)
unnamed: N4.5, U6.14 (5)
unnamed: N4.4, U6.13 (4)
unnamed: N4.3, U6.9 (3)
unnamed: N4.2, U6.8 (2)
unnamed: N4.1, U6.15 (1)
unnamed: N4.0, U6.16 (0)
unnamed: N4.A, R15.2

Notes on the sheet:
Nixie and Drivers
Nixie Tubes and Drivers
1.0
colon



Board: 2 copper layers, 150.0 x 88.0 mm, 90 parts (2 on the bottom side), 113 nets.

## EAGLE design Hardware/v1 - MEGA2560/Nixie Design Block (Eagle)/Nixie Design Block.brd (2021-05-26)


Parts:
R1: R-US_M0805; M0805
U$1: ИН-8; IN-8_SOCKET
U$2: K155ID1; DIL16-KIT

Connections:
unnamed: U$1.9, U$2.2 (9)
unnamed: U$1.8, U$2.1 (8)
unnamed: U$1.7, U$2.10 (7)
unnamed: U$1.6, U$2.11 (6)
unnamed: U$1.5, U$2.14 (5)
unnamed: U$1.4, U$2.13 (4)
unnamed: U$1.3, U$2.9 (3)
unnamed: U$1.2, U$2.8 (2)
unnamed: U$1.1, U$2.15 (1)
unnamed: U$1.0, U$2.16 (0)
unnamed: R1.2, U$1.A

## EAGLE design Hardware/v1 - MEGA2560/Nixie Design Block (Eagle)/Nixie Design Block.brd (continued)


Board: 2 copper layers, 40.6 x 46.9 mm, 3 parts (0 on the bottom side), 11 nets.

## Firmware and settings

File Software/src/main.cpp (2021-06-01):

#include <Arduino.h>

#include "power.h"
#include "debug.h"
#include "gps.h"
#include "nixie.h"
#include "rtc.h"
#ifdef PCB
  #include "pcbPins.h"
#else
  #include "megaPins.h"
#endif

void startUp();                                                       // Initializes the tubes to the current time when first powered

void setup() {
  int i;

  #ifdef DEBUG
    Serial.begin(115200);                                               // Sets Serial0 to 115200 Hz for debug printing
  #endif

  #ifdef GENERAL_DEBUG
    Serial.println("Starting");                                       // Indicates the the code has started
  #endif

  for(i = extra1; i <= dst; i++) {                                       // Sets all the pins for the setting switches as inputs with pullups
    pinMode(i, INPUT_PULLUP);                                       
  }

  nixieInit();                                                        // Setup all pins needed to control the tubes

  dimmingInit();                                                      // Sets the PWM frequency and tubes to full brightness

  nixieDisplay(minOnesA, minOnesB, minOnesC, minOnesD, 0);            // Sets the minute ones tube to display 0
  nixieDisplay(minTensA, minTensB, minTensC, minTensD, 0);            // Sets the minute tens tube to display 0
  nixieDisplay(hrOnesA, hrOnesB, hrOnesC, hrOnesD, 0);                // Sets the hour ones tube to display 0
  nixieDisplay(hrTensA, hrTensB, hrTensC, hrTensD, 0);                // Sets the hour tens tube to display 0

  gpsInit();                                                          // Initializes the GPS
}

void loop() {
  int minute, hour, oldMinute, oldHour;
  int minOnes, minTens, hourOnes, hourTens;

  startUp();                                                          // Runs the code needed to get everything started

  while(true) {
    dimming();                                                        // Sets the brightness of the nixie tubes based on ambient light

    getRTCTime(minute, hour);                                         // Gets the current time from the RTC

    if(minute != oldMinute) {                                         // Checks if the minute has updated since the last loop and updates display if it has
      minOnes = minute % 10;                                          // Uses mod 10 to get the ones digit of the minute
      minTens = (minute - minOnes) / 10;                              // Subtracts the ones digit from the current hour and divides by 10 to get the tens digit of the minute

      nixieDisplay(minOnesA, minOnesB, minOnesC, minOnesD, minOnes);  // Writes the current minute ones digit to the minute ones tube
      nixieDisplay(minTensA, minTensB, minTensC, minTensD, minTens);  // Writes the current minute tens digit to the minute tens tube

      oldMinute = minute;                                             // Updates the 'old' tracker to the new minute
    }

    if(hour != oldHour) {                                             // Checks if the hour has updated since the last loop and updates display if it has
      hourOnes = hour % 10;                                           // Uses mod 10 to get the ones digit of the hour
      hourTens = (hour - hourOnes) / 10;                              // Subtracts the ones digit from the current hour and divides by 10 to get the tens digit of the hour

      nixieDisplay(hrOnesA, hrOnesB, hrOnesC, hrOnesD, hourOnes);     // Writes the current hour ones digit to the hour ones tube
      nixieDisplay(hrTensA, hrTensB, hrTensC, hrTensD, hourTens);     // Writes the current hour tens digit to the hour tens tube

      oldHour = hour;                                                 // Updates the 'old tracker to the new hour
    }


    #ifdef TIME_DEBUG                                                 // Prints the current RTC time to the serial monitor in the standard hh:mm:ss format
      Serial.print("RTC Time: ");
      Serial.print(hourTens);
      Serial.print(hourOnes);
      Serial.print(":");
      Serial.print(minTens);
      Serial.print(minOnes);
      Serial.print("\n");
    #endif
    }
  }

// Initializes the tubes to the current time when first powered
void startUp() {
  int minute, hour;
  int minOnes, minTens, hourOnes, hourTens;
  int i, delaySpeed = 50;

  //programPD();

  RTCInit();                                                          // Sets the RTC time using the GPS or stored time from the battery backup functionality

  dimDown();                                                          // Dims the tubes to the current ambient light

  cycleDisplay(delaySpeed);                                           // Cycles the display for fanfare 
  
  getRTCTime(minute, hour);                                           // Pulls the current time from the RTC

  #ifdef TIME_DEBUG                                                   // Prints the initial time on startup
    Serial.print("Startup: ");
    Serial.print(hour);
    Serial.print(":");
    Serial.print(minute);
    Serial.print("\n");
  #endif

    minOnes = minute % 10;                                            // Uses mod 10 to get the ones digit of the minute
    Serial.println(minOnes);
    minTens = (minute - minOnes) / 10;                                // Subtracts the ones digit from the current hour and divides by 10 to get the tens digit of the minute
    Serial.println(minTens);

    hourOnes = hour % 10;                                             // Uses mod 10 to get the ones digit of the hour
    Serial.println(hourOnes);
    hourTens = (hour - hourOnes) / 10;                                // Subtracts the ones digit from the current hour and divides by 10 to get the tens digit of the hour
    Serial.println(hourTens);

  
  for(i = 0; i < 10; i++) {                                           // Cycles each tube from 0-9 until the each digit of the current time is on
    if(i <= minOnes) {                                                // Checks if the minute ones tube has reached the current time
      nixieDisplay(minOnesA, minOnesB, minOnesC, minOnesD, i);
    }
    if(i <= minTens) {                                                // Checks if the minute tens tube has reached the current time
      nixieDisplay(minTensA, minTensB, minTensC, minTensD, i);
    }
    if(i <= hourOnes) {                                               // Checks if the hour ones tube has reached the current time
      nixieDisplay(hrOnesA, hrOnesB, hrOnesC, hrOnesD, i);          
    }
    if(i <= hourTens) {                                               // Checks if the hour tens tube has reached the current time
      nixieDisplay(hrTensA, hrTensB, hrTensC, hrTensD, i);
    }

    delay(delaySpeed);
  }

  return;
}

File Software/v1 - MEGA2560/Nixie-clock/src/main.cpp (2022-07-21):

#include <Arduino.h>

#include "debug.h"
#include "gps.h"
#include "nixie.h"
#include "pins.h"
#include "nixie.h"
#include "rtc.h"
#include "settings.h"

void startUp(); // Initilizes system
/*
  initilizes rtc
  checks rtc status
    if power loss
      get time from gps
    else
      display current time
*/

void setup() {
  int i;
  
  #ifdef DEBUG
    Serial.begin(115200);
  #endif

  #ifdef GENERAL_DEBUG
    Serial.println("Starting");
  #endif
  
  gpsInit();

  settingsInit();

  nixieInit();

  rtcInit();
}

void loop() {
  // put your main code here, to run repeatedly:
}

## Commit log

2019-09-14 Changed GPS pins and added GPS power control pin
2019-09-14 Removed manufaturing files from the PCF8574 library
    [PCB_PCF8574.fzz, PCB_PCF8574_02.fzz, PCB_PCF8574_02_ic.fzz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]
2019-09-15 Added GPS power control functions
2019-12-18 changed pin definitions from defines to const ints and added dip switch time zone functionality
2019-12-18 changed 12 hour mode secection to a dip switch
2019-12-18 changed dip switch pins
2019-12-19 added ProMini to platform.ini
    [PCB_PCF8574.fzz, PCB_PCF8574_02.fzz, PCB_PCF8574_02_ic.fzz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]
2020-01-27 changed to arduino mega, re-assigned pins, adjusted functions to work without IO expanders
    [PCB_PCF8574.fzz, PCB_PCF8574_02.fzz, PCB_PCF8574_02_ic.fzz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]
2020-02-02 removed all reference to the IO expander and atmega328p controllers
    [PCB_PCF8574.fzz, PCB_PCF8574_02.fzz, PCB_PCF8574_02_ic.fzz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]
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2020-03-26 added pcb pins file and a toggle to switch between pins files in debug
2020-03-26 added pcb pins and ic labels
2020-03-26 added rtc interupt pin
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2020-03-27 moved switch reading from setRTCTime() to dedicated function that runs in getRTCTime()
2020-03-31 Added PWM minimum bounding and a pull to full brightness when close to max
2020-04-03 Added new PWM functions to lower frequency
2020-04-06 changed dimming pin to work with the PWM frequency library
2020-04-06 rearranged setting switch functions
2020-04-08 Added a dimming function that uses a pot for PWM tuning and lowered the min PWM value for 60Hz
2020-04-15 lowered voltage to trigger max brightness
2020-04-15 added rtc power loss recovery
2020-04-15 set tube brightness to max durrring setup
2020-04-15 removed powerloss check invert to work corectly
    [main.cpp, rtc.cpp]
2020-04-15 fixed initial pwm write argument order
    [nixie.cpp]
2020-12-27 Removed averaging code that was causing the PWM signal to be unstable
    [nixie.cpp]
2020-12-29 Found the ideal PWM frequency and added a 4.7uF capacitor to the output of the nixie supply to eliminate audible coil whine
2020-12-30 Modified to use the new npn dimming circuit
2020-12-31 Fixed minor formmating issues
    [nixie.cpp, rtc.cpp]
2021-01-04 Adjusted the maxPWM value for the new current limiting resistors
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2021-01-04 Changed programPD() to be hardcoded for 9V 2A (18W) instead of user controllable
2021-01-04 fixed order of operation error and found that wrire() was missing at the end of programPD()
    [power.cpp]
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2021-05-26 Added PCB files to Hardware
    [BOM.xlsx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]
2021-05-29 Added a toggle to set the RTS using current time when uploading code
2021-05-29 Changed the PWM pin from 4 to 5
2021-05-29 Changed the settings pins initilization order to match the PCB pin order
2021-05-29 Seperated minute and hour pin initilazation to match the PCB pin order and disabled PWM frequency control. PWM frequency control will be added back latter
2021-05-29 Added the ability to set RTC time when uploading code and switched from signed binary to multiply by -1 for setting the time zone
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2021-06-01 rearranged the hardware file structure and added the KiCad files
    [BOM.xlsx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]
2021-06-01 Moved all KiCad files into a dedicated folder
    [Nixie Clock.kicad_pcb, Nixie Clock.kicad_sch, communication.kicad_sch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]
2021-06-01 added comments about KiCad version used and what v1.05 is
2021-06-02 Added a minimum PWM value to keep the tubes from turning off or partially igniting in the dark
2023-09-29 Added folders for v2 and started hardware design
    [BOM.xlsx, Nixie Clock v1.0.brd, Nixie Clock v1.0.sch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]
2023-10-14 added schematic pages and HV switching circuit
    [MCU.kicad_sch, Nixie Clock v2.kicad_sch, nixie.kicad_sch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]
2023-10-22 Complteted schematic, mergerd schematic on to one sheet, started assigning footprints
    [MCU.kicad_sch, Nixie Clock v2.kicad_sch, nixie.kicad_sch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]
2023-10-22 removed empty schematic sheets left from the 1 page merge
    [MCU.kicad_sch, nixie.kicad_sch, settings_sensors.kicad_sch]
2023-10-23 Finished assigning footprints and started layout
    [Nixie Clock v2.kicad_pcb, Nixie Clock v2.kicad_sch]
2023-10-23 Continued work on layout
    [Nixie Clock v2.kicad_pcb, Nixie Clock v2.kicad_sch]
2024-08-23 replaced old nixie compontes with new library and replaced IO expander with QFN
    [Nixie Clock v2.kicad_pcb, Nixie Clock v2.kicad_sch]
2024-08-24 Creating seperate processing and nixie boards for furture modularity
    [Nixie v2 IN-8 Board.kicad_pcb, Nixie v2 IN-8 Board.kicad_sch, Nixie v2 Processor Board.kicad_pcb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]
2024-08-25 seperated the processor and nixie boards
    [Nixie v2 IN-8 Board.kicad_sch, Nixie v2 Processor Board.kicad_pcb, Nixie v2 Processor Board.kicad_sch]
2024-08-27 Assigned footprints
    [Nixie v2 IN-8 Board.kicad_pcb, Nixie v2 IN-8 Board.kicad_sch]
2024-09-01 Started board layout
    [Nixie Clock v2.kicad_pcb, Nixie Clock v2.kicad_sch, Nixie v2 IN-8 Board.kicad_pcb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]
2024-09-02 Laied out indivdual circuit blocks
    [Nixie v2 Processor Board.kicad_pcb, Nixie v2 Processor Board.kicad_sch]
2024-09-02 Started placing assembled blocks on the board and routing
    [Nixie v2 Processor Board.kicad_pcb, Nixie v2 Processor Board.kicad_sch]
2024-09-02 started nixie layout, added bleed resistor to HV cap
    [Nixie v2 IN-8 Board.kicad_pcb, Nixie v2 IN-8 Board.kicad_sch, Nixie v2 Processor Board.kicad_pcb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]
2024-09-02 Completed initial layout of the IN-8 board
    [Nixie v2 IN-8 Board.kicad_pcb]
2024-09-03 finished initial layout and swapped SDA/SCL on connector
    [Nixie v2 IN-8 Board.kicad_pcb, Nixie v2 IN-8 Board.kicad_sch, Nixie v2 Processor Board.kicad_pcb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]
2025-02-03 added ground via stitching, and baord names, version, designer, and date to silkscreen
    [Nixie v2 IN-8 Board.kicad_pcb, Nixie v2 Processor Board.kicad_pcb]

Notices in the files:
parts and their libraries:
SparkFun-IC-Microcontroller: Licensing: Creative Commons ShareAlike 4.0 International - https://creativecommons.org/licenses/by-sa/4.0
